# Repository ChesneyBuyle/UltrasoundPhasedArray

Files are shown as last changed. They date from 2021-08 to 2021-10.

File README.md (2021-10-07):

# UltrasoundPhasedArray
 Ultrasound phased array for directional transmission: construction, embedded software and python implementation

## General specifications
A low-cost, narrowband ultrasound phased array system for narrowbeam transmission is presented. 

The design features wide bandwidth MEMS loudspeakers (UT-P 2019, USound) with very small dimensions (5 x 7 mm). Dense loudspeaker arrays with small interelement spacing can be constructed, enabling grating lobe free beam patterns at high frequency. The current prototype can support up to 64 MEMS speakers. The amplitude and phase of each loudspeaker stage can be controlled with high resolution, respectively with 10-bit and 12-bit. The array itself is constructed using a 3D printer. 

<p align="center">
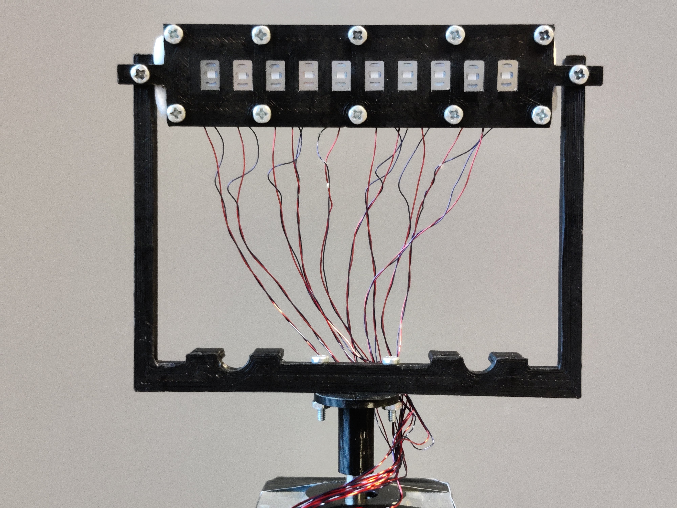
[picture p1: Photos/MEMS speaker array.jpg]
  
</p>

## System overview

Block diagram of the prototype:

<p align="center">
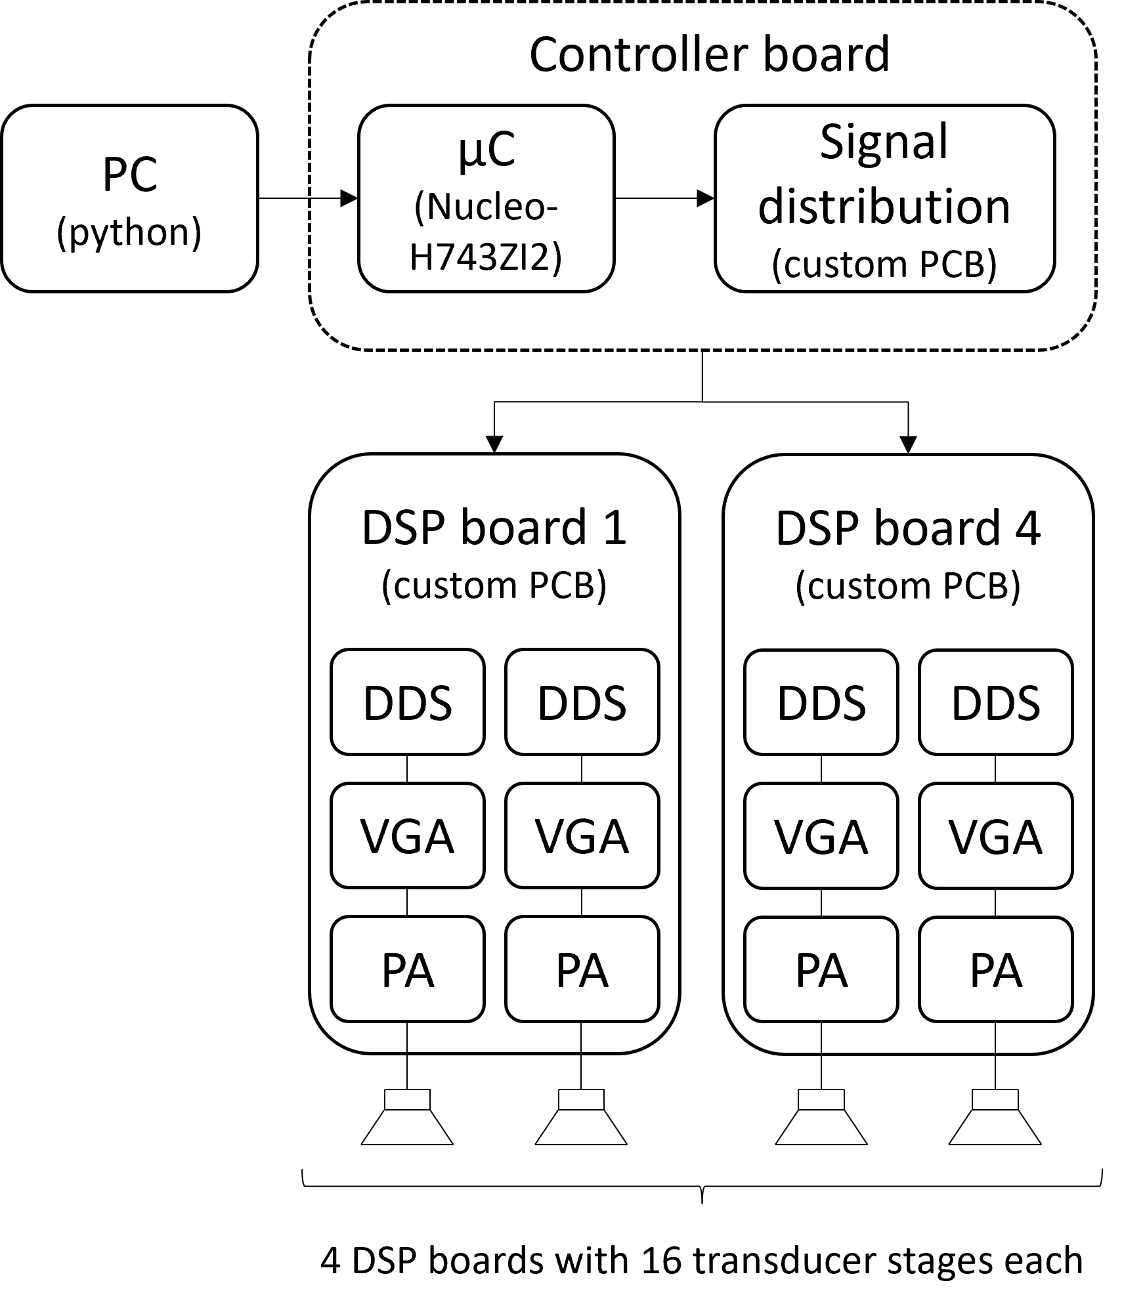
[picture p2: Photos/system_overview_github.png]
 
</p>

The loudspeaker array is controlled by an external computer. The phase delays and amplitudes of the loudspeaker stages are calculated according to the desired ultrasound beam pattern in Python. Next, these parameters are sent to a controller board, which consists of a NUCLEO-H743ZI2 microcontroller board and custom signal distribution PCB. 
* The microcontroller sends the transducer stage parameters to the corresponding DSP boards. The DSP boards contain the signal generation and amplifier hardware blocks of the loudspeaker stages. 
* The microcontroller uses the signal distribution board to distribute a common clock signal to the DSP boards (for phase coherence) and it ensures communication to the correct hardware blocks. 

## Folder structure
* The *3D prints* folder contains the necessary STL-files to print the array. The loudspeakers should first be placed inside the *holder part (part 1)*. Next, the *cover part (part 2)* can be attached to the back of the array (side with connections on the MEMS loudspeakers) using M2 bolts. This keeps the MEMS loudspeakers in place when soldering the signal wires. Hence, now you should be able to solder the signal wires to the loudspeaker elements. We used very thin 0.25mm coated copper wire, because the loudspeaker connections are very fragile. Finally, we placed a thin layer of acoustic foam on the back of array and kept it into place using the *wire cover part (part 3)*. It also ensures that the signal wires and thus MEMS loudspeakers do not move anymore. 

* The *Python* folder contains the Python scripts for control over the transducer stages (controller.py and main.py). Furthermore, the Python scripts for sampling of the microphone signal (daq.py), stepper motor control (stepper.py) and plotting (plotter.py) are also available. Note that some paths may need to updated before the code runs correctly.

* The *PCB design files* folder contains the schematic and board files of the custom signal distribution and DSP boards (DDS, VGA and power amplifier). These were designed in Eagle. 

* The *Controller board code* contains the embedded code for the NUCLEO-H743ZI2 microcontroller board.

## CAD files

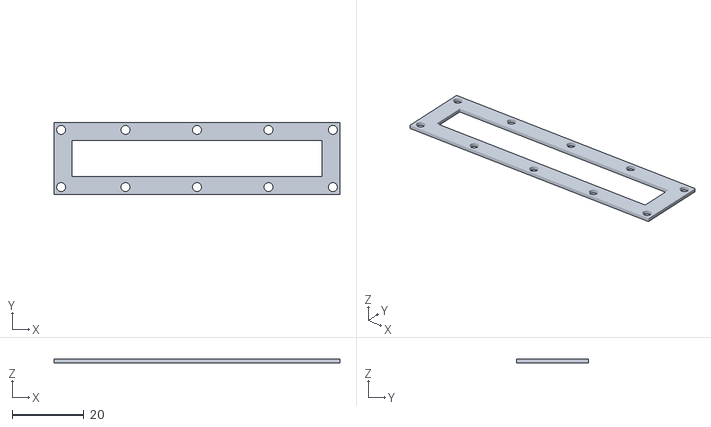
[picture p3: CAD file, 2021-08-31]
3D prints/1x10 loudspeaker array (part 3 - wire cover).stl
80.0 x 20.0 x 1.00

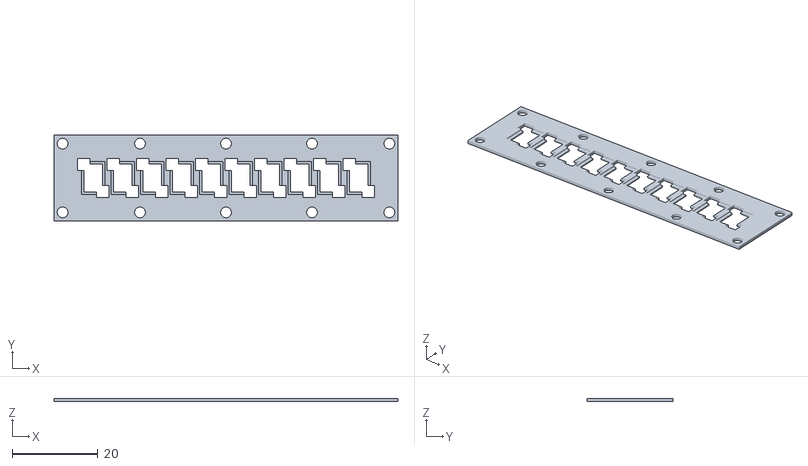
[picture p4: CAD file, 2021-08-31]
3D prints/1x10 loudspeaker array (part 2 - cover).stl
80.0 x 20.0 x 0.8

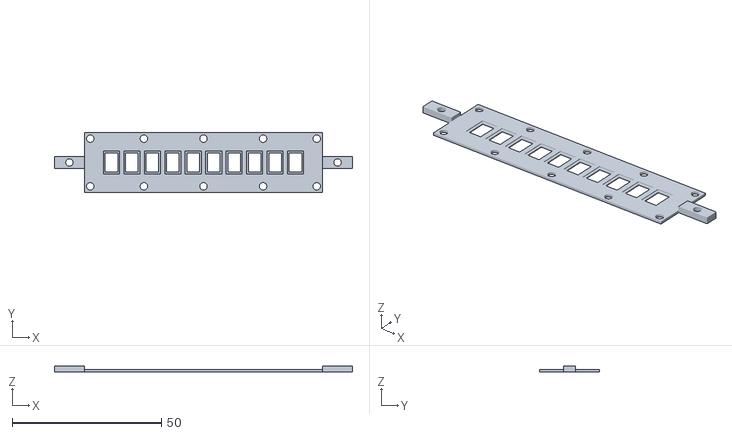
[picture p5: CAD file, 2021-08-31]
3D prints/1x10 loudspeaker array (part 1 - holder).stl
100.0 x 20.0 x 2.00

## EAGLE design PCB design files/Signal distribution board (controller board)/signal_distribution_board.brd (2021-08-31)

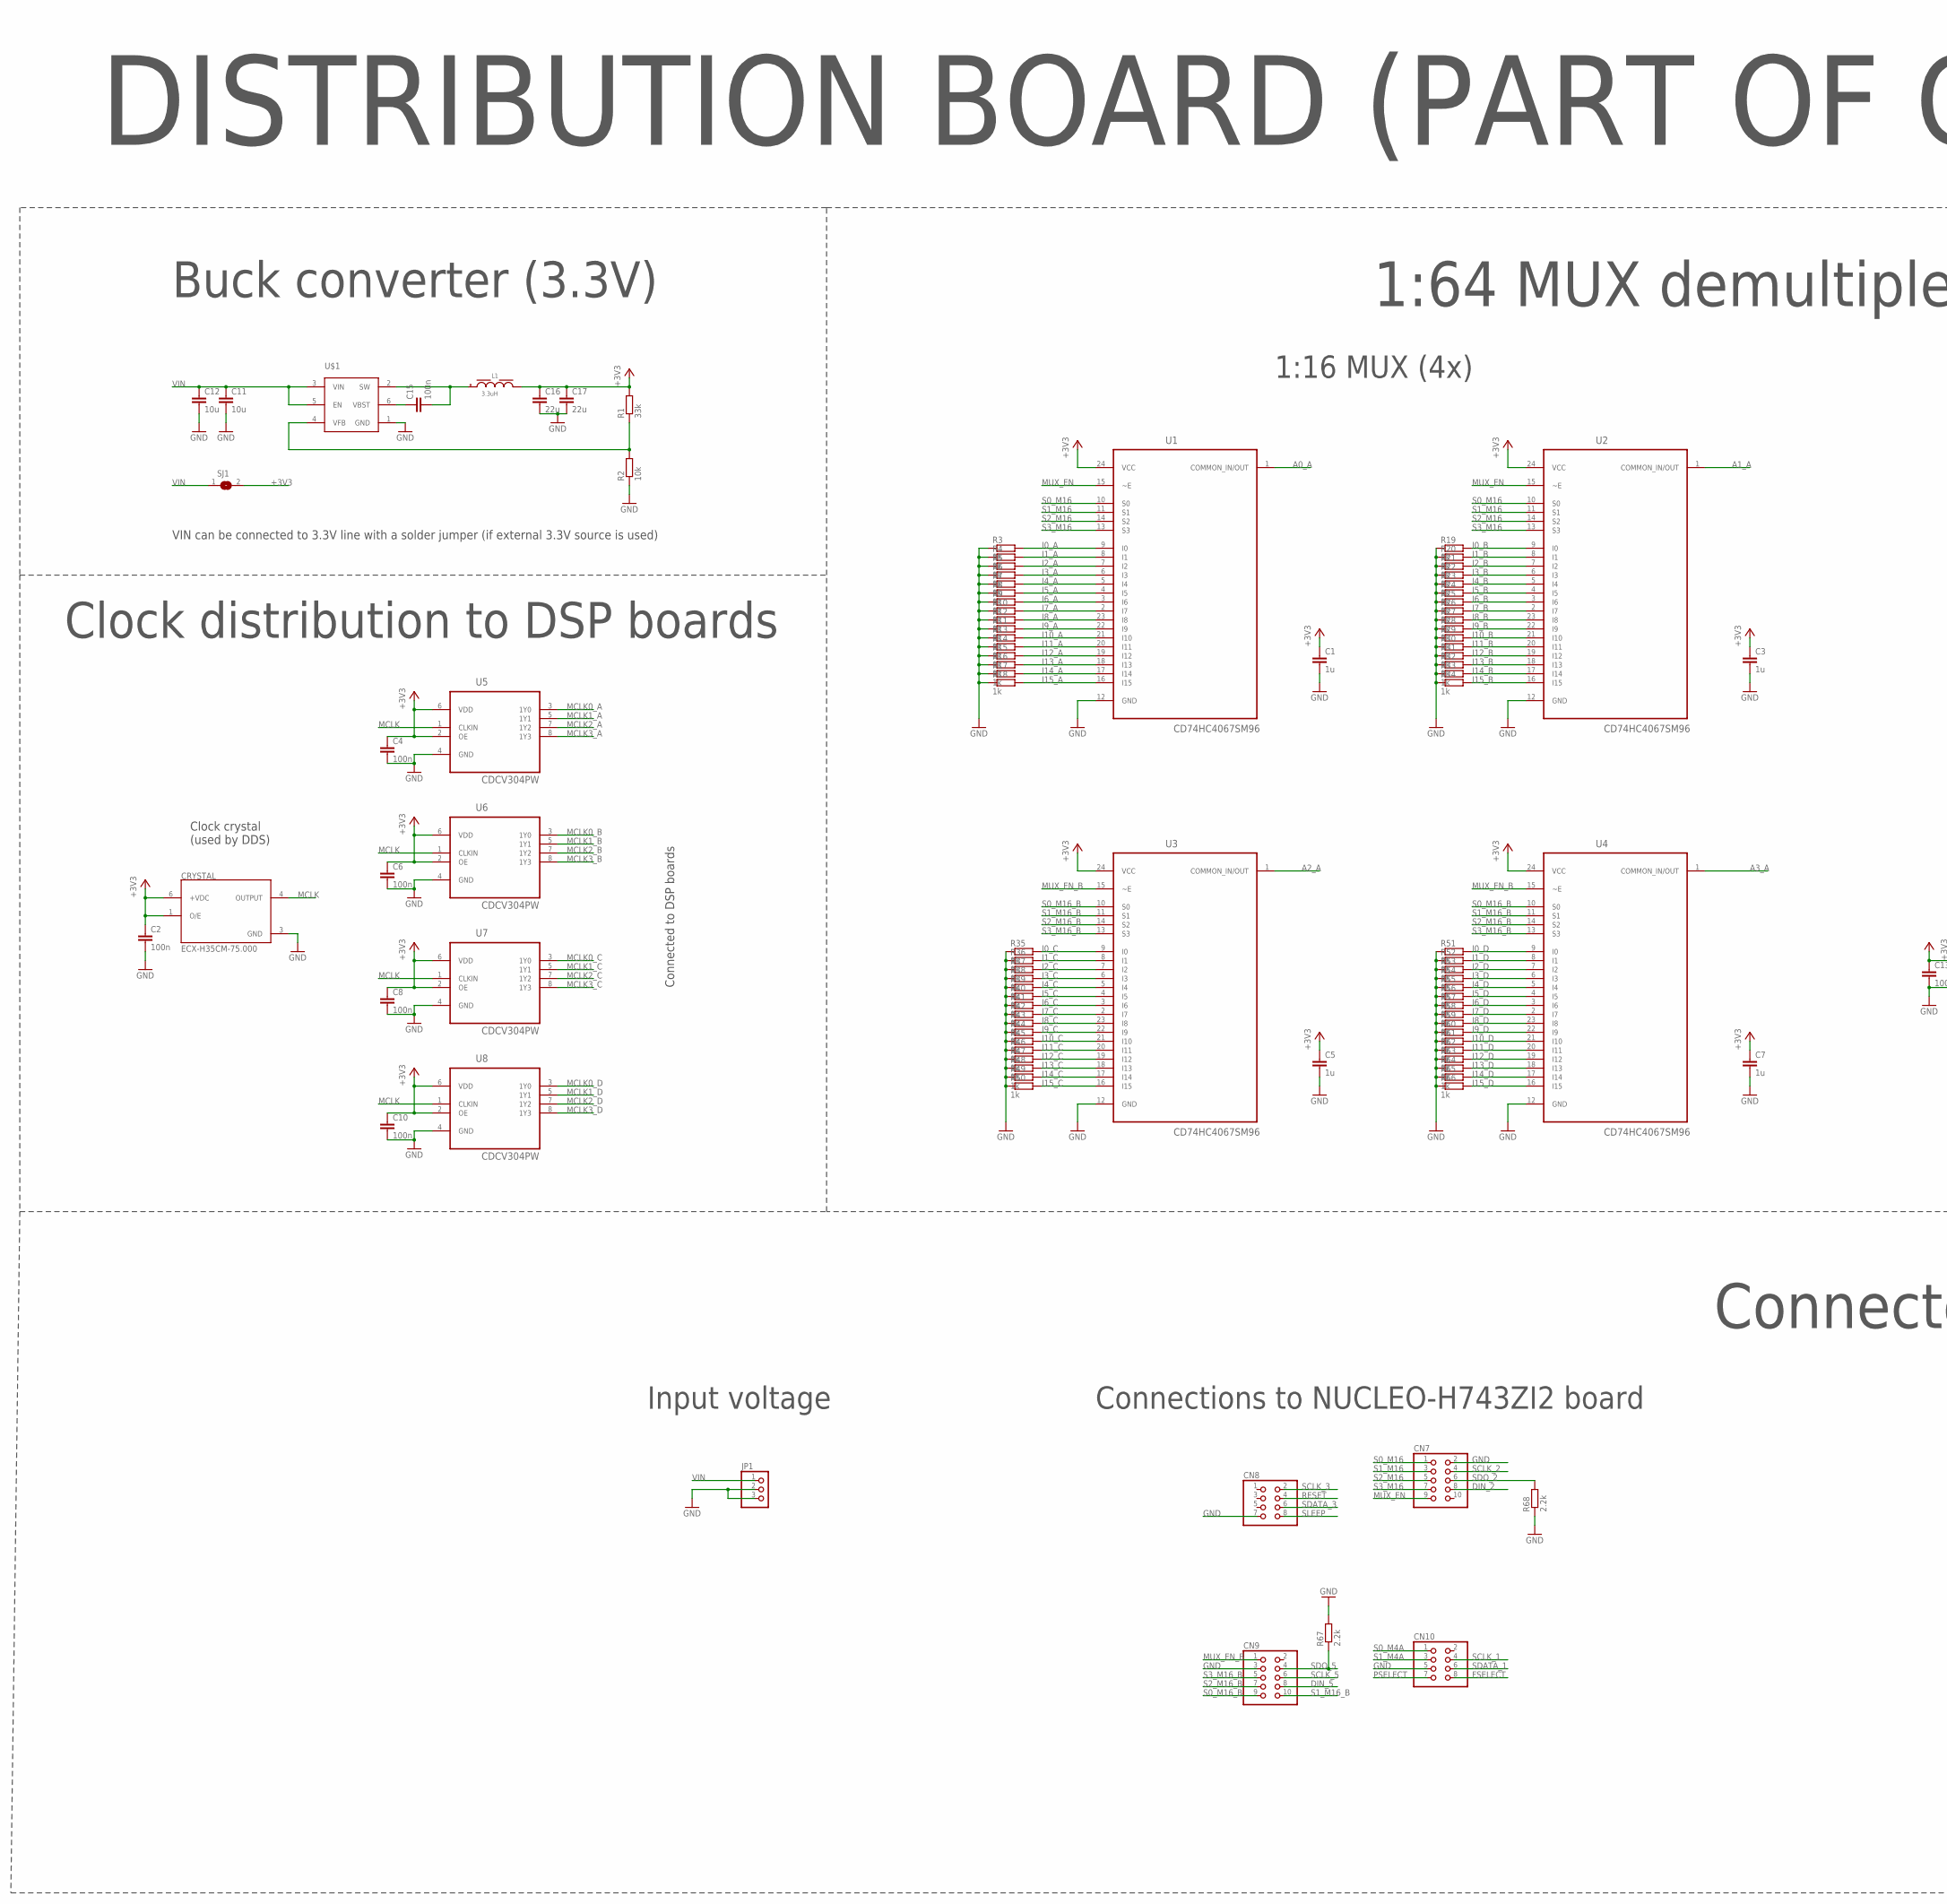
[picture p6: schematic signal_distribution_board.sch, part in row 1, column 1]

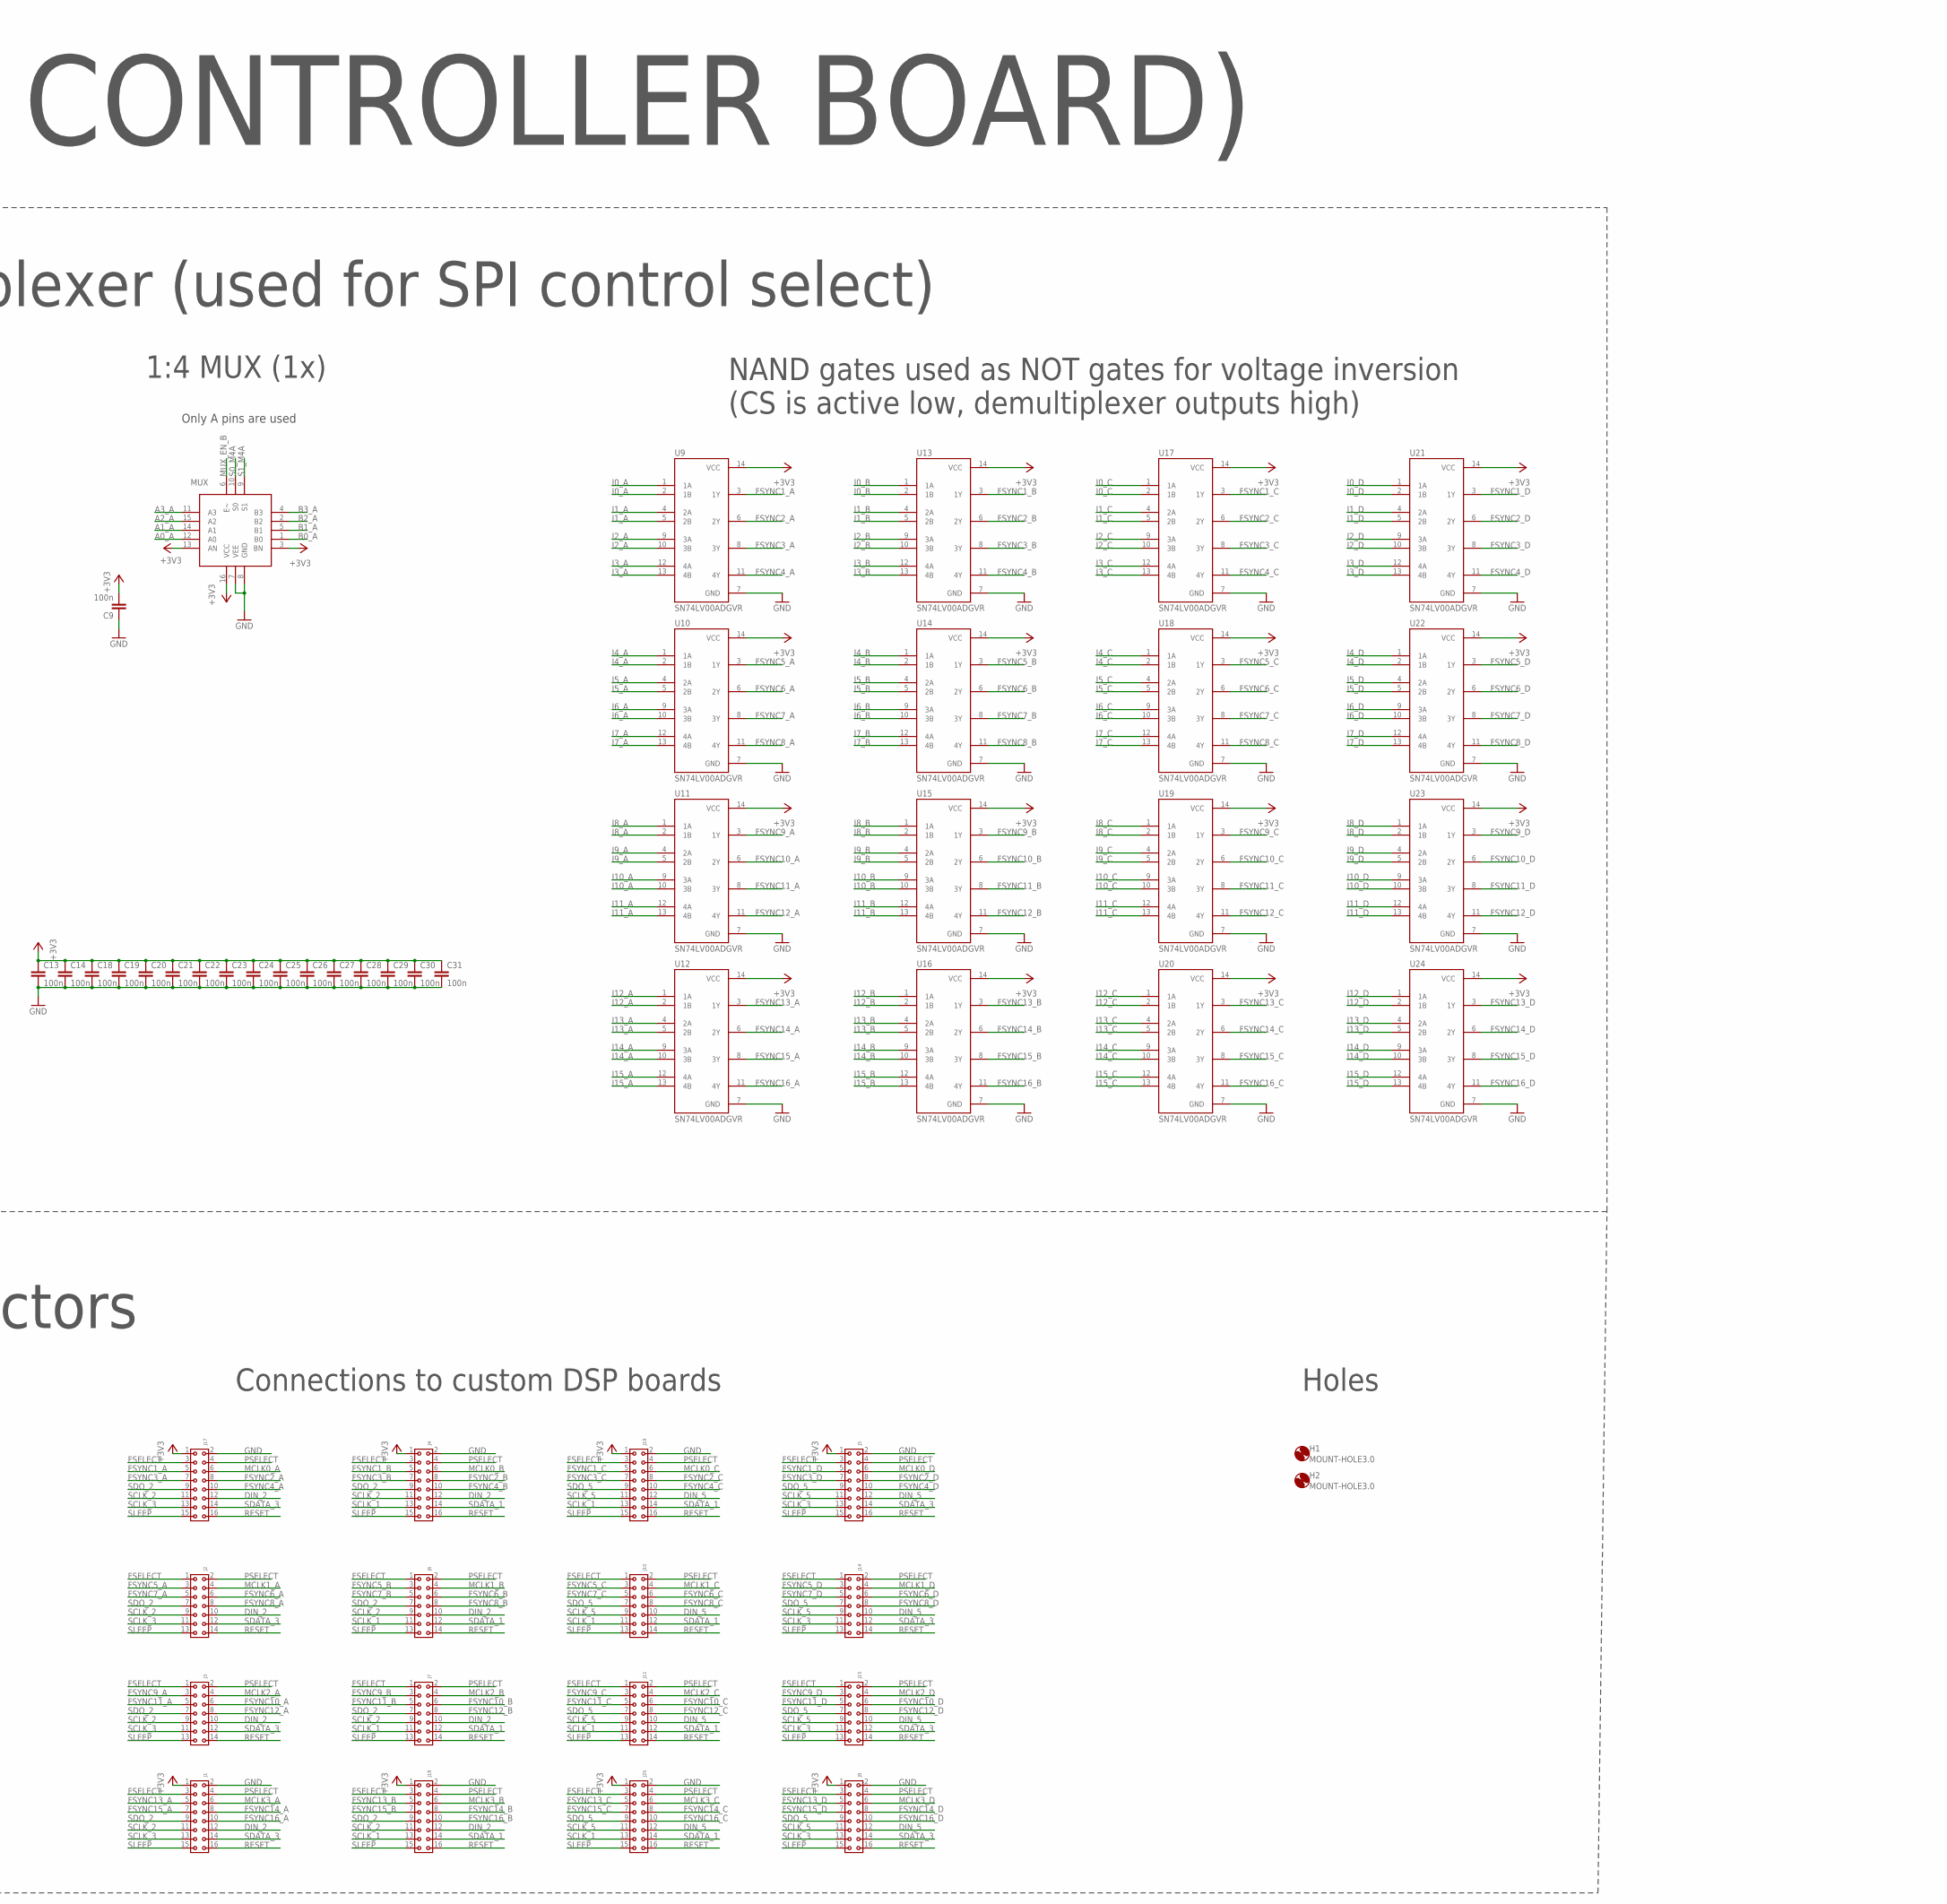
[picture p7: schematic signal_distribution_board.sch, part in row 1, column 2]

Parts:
C1, C3, C5, C7: 1u; C0603
C2, C4, C6, C8, C9, C10, C13, C14, C15, C18, C19, C20, C21, C22, C23, C24, C25, C26, C27, C28, C29, C30, C31: 100n; C0603
C11, C12: 10u; C0805
C16, C17: 22u; C1206
CN7, CN9: PINHD-2X5; 2X05
CN8, CN10: PINHD-2X4; 2X04
CRYSTAL: ECX-H35CM-75.000; OSC_ECX-H35CM-75.000
H1, H2: MOUNT-HOLE3.0; 3,0
J1, J4, J5, J8, J17, J18, J19, J20: 6130XX243121_613016243121; 613016243121
J2, J3, J6, J7, J10, J11, J14, J15: 6130XX243121_613014243121; 613014243121
JP1: PINHD-1X3; 1X03
L1: 3.3uH; WE-PD_7345P
MUX: CD74HC4052M96; SOIC127P600X175-16N
R1: 33k; R0603
R2: 10k; R0603
R3, R4, R5, R6, R7, R8, R9, R10, R11, R12, R13, R14, R15, R16, R17, R18, R19, R20, R21, R22, R23, R24, R25, R26, R27, R28, R29, R30, R31, R32, R33, R34, R35, R36, R37, R38, R39, R40, R41, R42, R43, R44, R45, R46, R47, R48, R49, R50, R51, R52, R53, R54, R55, R56, R57, R58, R59, R60, R61, R62, R63, R64, R65, R66: 1k; R0603
R67, R68: 2.2k; R0805
SJ1: SJ
U1, U2, U3, U4: CD74HC4067SM96; SOP65P780X200-24N
U5, U6, U7, U8: CDCV304PW; SOP65P640X120-8N
U9, U10, U11, U12, U13, U14, U15, U16, U17, U18, U19, U20, U21, U22, U23, U24: SN74LV00ADGVR; SOP40P640X120-14N
U$1: TPS562209; SOT95P280X110-6N

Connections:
+3V3: C1.1, C2.1, C3.1, C4.1, C5.1, C6.1, C7.1, C8.1, C9.2, C10.1, C13.1, C14.1, C16.1, C17.1, C18.1, C19.1, C20.1, C21.1, C22.1, C23.1, C24.1, C25.1, C26.1, C27.1, C28.1, C29.1, C30.1, C31.1, CRYSTAL.1 (O/E), CRYSTAL.6 (+VDC), J1.1, J4.1, J5.1, J8.1, J17.1, J18.1, J19.1, J20.1, L1.2, MUX.3 (BN), MUX.13 (AN), MUX.16 (VCC), R1.2, SJ1.2, U1.24 (VCC), U2.24 (VCC), U3.24 (VCC), U4.24 (VCC), U5.2 (OE), U5.6 (VDD), U6.2 (OE), U6.6 (VDD), U7.2 (OE), U7.6 (VDD), U8.2 (OE), U8.6 (VDD), U9.14 (VCC), U10.14 (VCC), U11.14 (VCC), U12.14 (VCC), U13.14 (VCC), U14.14 (VCC), U15.14 (VCC), U16.14 (VCC), U17.14 (VCC), U18.14 (VCC), U19.14 (VCC), U20.14 (VCC), U21.14 (VCC), U22.14 (VCC), U23.14 (VCC), U24.14 (VCC)
A0_A: MUX.12 (A0), U1.1 (COMMON_IN/OUT)
A1_A: MUX.14 (A1), U2.1 (COMMON_IN/OUT)
A2_A: MUX.15 (A2), U3.1 (COMMON_IN/OUT)
A3_A: MUX.11 (A3), U4.1 (COMMON_IN/OUT)
B0_A: MUX.1 (B0)
B1_A: MUX.5 (B1)
B2_A: MUX.2 (B2)
B3_A: MUX.4 (B3)
DIN_2: CN7.8, J1.12, J2.10, J3.10, J4.12, J6.10, J7.10, J17.12, J18.12
DIN_5: CN9.8, J5.12, J8.12, J10.10, J11.10, J14.10, J15.10, J19.12, J20.12
FSELECT: CN10.8, J1.3, J2.1, J3.1, J4.3, J5.3, J6.1, J7.1, J8.3, J10.1, J11.1, J14.1, J15.1, J17.3, J18.3, J19.3, J20.3
FSYNC1_A: J17.5, U9.3 (1Y)
FSYNC1_B: J4.5, U13.3 (1Y)
FSYNC1_C: J19.5, U17.3 (1Y)
FSYNC1_D: J5.5, U21.3 (1Y)
FSYNC2_A: J17.8, U9.6 (2Y)
FSYNC2_B: J4.8, U13.6 (2Y)
FSYNC2_C: J19.8, U17.6 (2Y)
FSYNC2_D: J5.8, U21.6 (2Y)
FSYNC3_A: J17.7, U9.8 (3Y)
FSYNC3_B: J4.7, U13.8 (3Y)
FSYNC3_C: J19.7, U17.8 (3Y)
FSYNC3_D: J5.7, U21.8 (3Y)
FSYNC4_A: J17.10, U9.11 (4Y)
FSYNC4_B: J4.10, U13.11 (4Y)
FSYNC4_C: J19.10, U17.11 (4Y)
FSYNC4_D: J5.10, U21.11 (4Y)
FSYNC5_A: J2.3, U10.3 (1Y)
FSYNC5_B: J6.3, U14.3 (1Y)
FSYNC5_C: J10.3, U18.3 (1Y)
FSYNC5_D: J14.3, U22.3 (1Y)
FSYNC6_A: J2.6, U10.6 (2Y)
FSYNC6_B: J6.6, U14.6 (2Y)
FSYNC6_C: J10.6, U18.6 (2Y)
FSYNC6_D: J14.6, U22.6 (2Y)
FSYNC7_A: J2.5, U10.8 (3Y)
FSYNC7_B: J6.5, U14.8 (3Y)
FSYNC7_C: J10.5, U18.8 (3Y)
FSYNC7_D: J14.5, U22.8 (3Y)
FSYNC8_A: J2.8, U10.11 (4Y)
FSYNC8_B: J6.8, U14.11 (4Y)
FSYNC8_C: J10.8, U18.11 (4Y)
FSYNC8_D: J14.8, U22.11 (4Y)
FSYNC9_A: J3.3, U11.3 (1Y)
FSYNC9_B: J7.3, U15.3 (1Y)
FSYNC9_C: J11.3, U19.3 (1Y)
FSYNC9_D: J15.3, U23.3 (1Y)
FSYNC10_A: J3.6, U11.6 (2Y)
FSYNC10_B: J7.6, U15.6 (2Y)
FSYNC10_C: J11.6, U19.6 (2Y)
FSYNC10_D: J15.6, U23.6 (2Y)
FSYNC11_A: J3.5, U11.8 (3Y)
FSYNC11_B: J7.5, U15.8 (3Y)
FSYNC11_C: J11.5, U19.8 (3Y)
FSYNC11_D: J15.5, U23.8 (3Y)
FSYNC12_A: J3.8, U11.11 (4Y)
FSYNC12_B: J7.8, U15.11 (4Y)
FSYNC12_C: J11.8, U19.11 (4Y)
FSYNC12_D: J15.8, U23.11 (4Y)
FSYNC13_A: J1.5, U12.3 (1Y)
FSYNC13_B: J18.5, U16.3 (1Y)
FSYNC13_C: J20.5, U20.3 (1Y)
FSYNC13_D: J8.5, U24.3 (1Y)
FSYNC14_A: J1.8, U12.6 (2Y)
FSYNC14_B: J18.8, U16.6 (2Y)
FSYNC14_C: J20.8, U20.6 (2Y)
FSYNC14_D: J8.8, U24.6 (2Y)
FSYNC15_A: J1.7, U12.8 (3Y)
FSYNC15_B: J18.7, U16.8 (3Y)
FSYNC15_C: J20.7, U20.8 (3Y)
FSYNC15_D: J8.7, U24.8 (3Y)
FSYNC16_A: J1.10, U12.11 (4Y)
FSYNC16_B: J18.10, U16.11 (4Y)
FSYNC16_C: J20.10, U20.11 (4Y)
FSYNC16_D: J8.10, U24.11 (4Y)
GND: C1.2, C2.2, C3.2, C4.2, C5.2, C6.2, C7.2, C8.2, C9.1, C10.2, C11.2, C12.2, C13.2, C14.2, C16.2, C17.2, C18.2, C19.2, C20.2, C21.2, C22.2, C23.2, C24.2, C25.2, C26.2, C27.2, C28.2, C29.2, C30.2, C31.2, CN7.2, CN8.7, CN9.3, CN10.5, CRYSTAL.3 (GND), J1.2, J4.2, J5.2, J8.2, J17.2, J18.2, J19.2, J20.2, JP1.2, JP1.3, MUX.7 (VEE), MUX.8 (GND), R2.1, R3.1, R4.1, R5.1, R6.1, R7.1, R8.1, R9.1, R10.1, R11.1, R12.1, R13.1, R14.1, R15.1, R16.1, R17.1, R18.1, R19.1, R20.1, R21.1, R22.1, R23.1, R24.1, R25.1, R26.1, R27.1, R28.1, R29.1, R30.1, R31.1, R32.1, R33.1, R34.1, R35.1, R36.1, R37.1, R38.1, R39.1, R40.1, R41.1, R42.1, R43.1, R44.1, R45.1, R46.1, R47.1, R48.1, R49.1, R50.1, R51.1, R52.1, R53.1, R54.1, R55.1, R56.1, R57.1, R58.1, R59.1, R60.1, R61.1, R62.1, R63.1, R64.1, R65.1, R66.1, R67.2, R68.1, U1.12 (GND), U2.12 (GND), U3.12 (GND), U4.12 (GND), U5.4 (GND), U6.4 (GND), U7.4 (GND), U8.4 (GND), U9.7 (GND), U10.7 (GND), U11.7 (GND), U12.7 (GND), U13.7 (GND), U14.7 (GND), U15.7 (GND), U16.7 (GND), U17.7 (GND), U18.7 (GND), U19.7 (GND), U20.7 (GND), U21.7 (GND), U22.7 (GND), U23.7 (GND), U24.7 (GND), U$1.1 (GND)
I0_A: R3.2, U1.9 (I0), U9.1 (1A), U9.2 (1B)
I0_B: R19.2, U2.9 (I0), U13.1 (1A), U13.2 (1B)
I0_C: R35.2, U3.9 (I0), U17.1 (1A), U17.2 (1B)
I0_D: R51.2, U4.9 (I0), U21.1 (1A), U21.2 (1B)
I1_A: R4.2, U1.8 (I1), U9.4 (2A), U9.5 (2B)
I1_B: R20.2, U2.8 (I1), U13.4 (2A), U13.5 (2B)
I1_C: R36.2, U3.8 (I1), U17.4 (2A), U17.5 (2B)
I1_D: R52.2, U4.8 (I1), U21.4 (2A), U21.5 (2B)
I2_A: R5.2, U1.7 (I2), U9.9 (3A), U9.10 (3B)
I2_B: R21.2, U2.7 (I2), U13.9 (3A), U13.10 (3B)
I2_C: R37.2, U3.7 (I2), U17.9 (3A), U17.10 (3B)
I2_D: R53.2, U4.7 (I2), U21.9 (3A), U21.10 (3B)
I3_A: R6.2, U1.6 (I3), U9.12 (4A), U9.13 (4B)
I3_B: R22.2, U2.6 (I3), U13.12 (4A), U13.13 (4B)
I3_C: R38.2, U3.6 (I3), U17.12 (4A), U17.13 (4B)
I3_D: R54.2, U4.6 (I3), U21.12 (4A), U21.13 (4B)
I4_A: R7.2, U1.5 (I4), U10.1 (1A), U10.2 (1B)
I4_B: R23.2, U2.5 (I4), U14.1 (1A), U14.2 (1B)
I4_C: R39.2, U3.5 (I4), U18.1 (1A), U18.2 (1B)
I4_D: R55.2, U4.5 (I4), U22.1 (1A), U22.2 (1B)
I5_A: R8.2, U1.4 (I5), U10.4 (2A), U10.5 (2B)
I5_B: R24.2, U2.4 (I5), U14.4 (2A), U14.5 (2B)
I5_C: R40.2, U3.4 (I5), U18.4 (2A), U18.5 (2B)
I5_D: R56.2, U4.4 (I5), U22.4 (2A), U22.5 (2B)
I6_A: R9.2, U1.3 (I6), U10.9 (3A), U10.10 (3B)
I6_B: R25.2, U2.3 (I6), U14.9 (3A), U14.10 (3B)
I6_C: R41.2, U3.3 (I6), U18.9 (3A), U18.10 (3B)
I6_D: R57.2, U4.3 (I6), U22.9 (3A), U22.10 (3B)
I7_A: R10.2, U1.2 (I7), U10.12 (4A), U10.13 (4B)
I7_B: R26.2, U2.2 (I7), U14.12 (4A), U14.13 (4B)
I7_C: R42.2, U3.2 (I7), U18.12 (4A), U18.13 (4B)
I7_D: R58.2, U4.2 (I7), U22.12 (4A), U22.13 (4B)
I8_A: R12.2, U1.23 (I8), U11.1 (1A), U11.2 (1B)
I8_B: R27.2, U2.23 (I8), U15.1 (1A), U15.2 (1B)
I8_C: R43.2, U3.23 (I8), U19.1 (1A), U19.2 (1B)
I8_D: R59.2, U4.23 (I8), U23.1 (1A), U23.2 (1B)
I9_A: R11.2, U1.22 (I9), U11.4 (2A), U11.5 (2B)
I9_B: R28.2, U2.22 (I9), U15.4 (2A), U15.5 (2B)
I9_C: R44.2, U3.22 (I9), U19.4 (2A), U19.5 (2B)
I9_D: R60.2, U4.22 (I9), U23.4 (2A), U23.5 (2B)
I10_A: R13.2, U1.21 (I10), U11.9 (3A), U11.10 (3B)
I10_B: R29.2, U2.21 (I10), U15.9 (3A), U15.10 (3B)
I10_C: R45.2, U3.21 (I10), U19.9 (3A), U19.10 (3B)
I10_D: R61.2, U4.21 (I10), U23.9 (3A), U23.10 (3B)
I11_A: R14.2, U1.20 (I11), U11.12 (4A), U11.13 (4B)
I11_B: R30.2, U2.20 (I11), U15.12 (4A), U15.13 (4B)
I11_C: R46.2, U3.20 (I11), U19.12 (4A), U19.13 (4B)
I11_D: R62.2, U4.20 (I11), U23.12 (4A), U23.13 (4B)
I12_A: R15.2, U1.19 (I12), U12.1 (1A), U12.2 (1B)
I12_B: R31.2, U2.19 (I12), U16.1 (1A), U16.2 (1B)
I12_C: R47.2, U3.19 (I12), U20.1 (1A), U20.2 (1B)
I12_D: R63.2, U4.19 (I12), U24.1 (1A), U24.2 (1B)
I13_A: R16.2, U1.18 (I13), U12.4 (2A), U12.5 (2B)
I13_B: R32.2, U2.18 (I13), U16.4 (2A), U16.5 (2B)
I13_C: R48.2, U3.18 (I13), U20.4 (2A), U20.5 (2B)
I13_D: R64.2, U4.18 (I13), U24.4 (2A), U24.5 (2B)
I14_A: R17.2, U1.17 (I14), U12.9 (3A), U12.10 (3B)
I14_B: R33.2, U2.17 (I14), U16.9 (3A), U16.10 (3B)
I14_C: R49.2, U3.17 (I14), U20.9 (3A), U20.10 (3B)
I14_D: R65.2, U4.17 (I14), U24.9 (3A), U24.10 (3B)
I15_A: R18.2, U1.16 (I15), U12.12 (4A), U12.13 (4B)
I15_B: R34.2, U2.16 (I15), U16.12 (4A), U16.13 (4B)
I15_C: R50.2, U3.16 (I15), U20.12 (4A), U20.13 (4B)
I15_D: R66.2, U4.16 (I15), U24.12 (4A), U24.13 (4B)
MCLK: CRYSTAL.4 (OUTPUT), U5.1 (CLKIN), U6.1 (CLKIN), U7.1 (CLKIN), U8.1 (CLKIN)
MCLK0_A: J17.6, U5.3 (1Y0)
MCLK0_B: J4.6, U6.3 (1Y0)
MCLK0_C: J19.6, U7.3 (1Y0)
MCLK0_D: J5.6, U8.3 (1Y0)
MCLK1_A: J2.4, U5.5 (1Y1)
MCLK1_B: J6.4, U6.5 (1Y1)
MCLK1_C: J10.4, U7.5 (1Y1)
MCLK1_D: J14.4, U8.5 (1Y1)
MCLK2_A: J3.4, U5.7 (1Y2)
MCLK2_B: J7.4, U6.7 (1Y2)
MCLK2_C: J11.4, U7.7 (1Y2)
MCLK2_D: J15.4, U8.7 (1Y2)
MCLK3_A: J1.6, U5.8 (1Y3)
MCLK3_B: J18.6, U6.8 (1Y3)
MCLK3_C: J20.6, U7.8 (1Y3)
MCLK3_D: J8.6, U8.8 (1Y3)
MUX_EN: CN7.9, U1.15 (~E), U2.15 (~E)
MUX_EN_B: CN9.1, MUX.6 (E~), U3.15 (~E), U4.15 (~E)
unnamed: C15.1, U$1.6 (VBST)
unnamed: R1.1, R2.2, U$1.4 (VFB)
unnamed: C15.2, L1.1, U$1.2 (SW)
PSELECT: CN10.7, J1.4, J2.2, J3.2, J4.4, J5.4, J6.2, J7.2, J8.4, J10.2, J11.2, J14.2, J15.2, J17.4, J18.4, J19.4, J20.4
RESET: CN8.4, J1.16, J2.14, J3.14, J4.16, J5.16, J6.14, J7.14, J8.16, J10.14, J11.14, J14.14, J15.14, J17.16, J18.16, J19.16, J20.16
S0_M4A: CN10.1, MUX.10 (S0)
S0_M16: CN7.1, U1.10 (S0), U2.10 (S0)
S0_M16_B: CN9.9, U3.10 (S0), U4.10 (S0)
S1_M4A: CN10.3, MUX.9 (S1)
S1_M16: CN7.3, U1.11 (S1), U2.11 (S1)
S1_M16_B: CN9.10, U3.11 (S1), U4.11 (S1)
S2_M16: CN7.5, U1.14 (S2), U2.14 (S2)
S2_M16_B: CN9.7, U3.14 (S2), U4.14 (S2)
S3_M16: CN7.7, U1.13 (S3), U2.13 (S3)
S3_M16_B: CN9.5, U3.13 (S3), U4.13 (S3)
SCLK_1: CN10.4, J4.13, J6.11, J7.11, J10.11, J11.11, J18.13, J19.13, J20.13
SCLK_2: CN7.4, J1.11, J2.9, J3.9, J4.11, J6.9, J7.9, J17.11, J18.11
SCLK_3: CN8.2, J1.13, J2.11, J3.11, J5.13, J8.13, J14.11, J15.11, J17.13
SCLK_5: CN9.6, J5.11, J8.11, J10.9, J11.9, J14.9, J15.9, J19.11, J20.11
SDATA_1: CN10.6, J4.14, J6.12, J7.12, J10.12, J11.12, J18.14, J19.14, J20.14
SDATA_3: CN8.6, J1.14, J2.12, J3.12, J5.14, J8.14, J14.12, J15.12, J17.14
SDO_2: CN7.6, J1.9, J2.7, J3.7, J4.9, J6.7, J7.7, J17.9, J18.9, R68.2
SDO_5: CN9.4, J5.9, J8.9, J10.7, J11.7, J14.7, J15.7, J19.9, J20.9, R67.1
SLEEP: CN8.8, J1.15, J2.13, J3.13, J4.15, J5.15, J6.13, J7.13, J8.15, J10.13, J11.13, J14.13, J15.13, J17.15, J18.15, J19.15, J20.15
VIN: C11.1, C12.1, JP1.1, SJ1.1, U$1.3 (VIN), U$1.5 (EN)

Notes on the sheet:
Clock distribution to DSP boards
Buck converter (3.3V)
Connectors
1:64 MUX demultiplexer (used for SPI control select)
VIN can be connected to 3.3V line with a solder jumper (if external 3.3V source is used)
Connected to DSP boards
Clock crystal (used by DDS)
1:16 MUX (4x)
1:4 MUX (1x)
Only A pins are used
NAND gates used as NOT gates for voltage inversion (CS is active low, demultiplexer outputs high)
Connections to NUCLEO-H743ZI2 board
Input voltage
Connections to custom DSP boards
Holes
DISTRIBUTION BOARD (PART OF CONTROLLER BOARD)

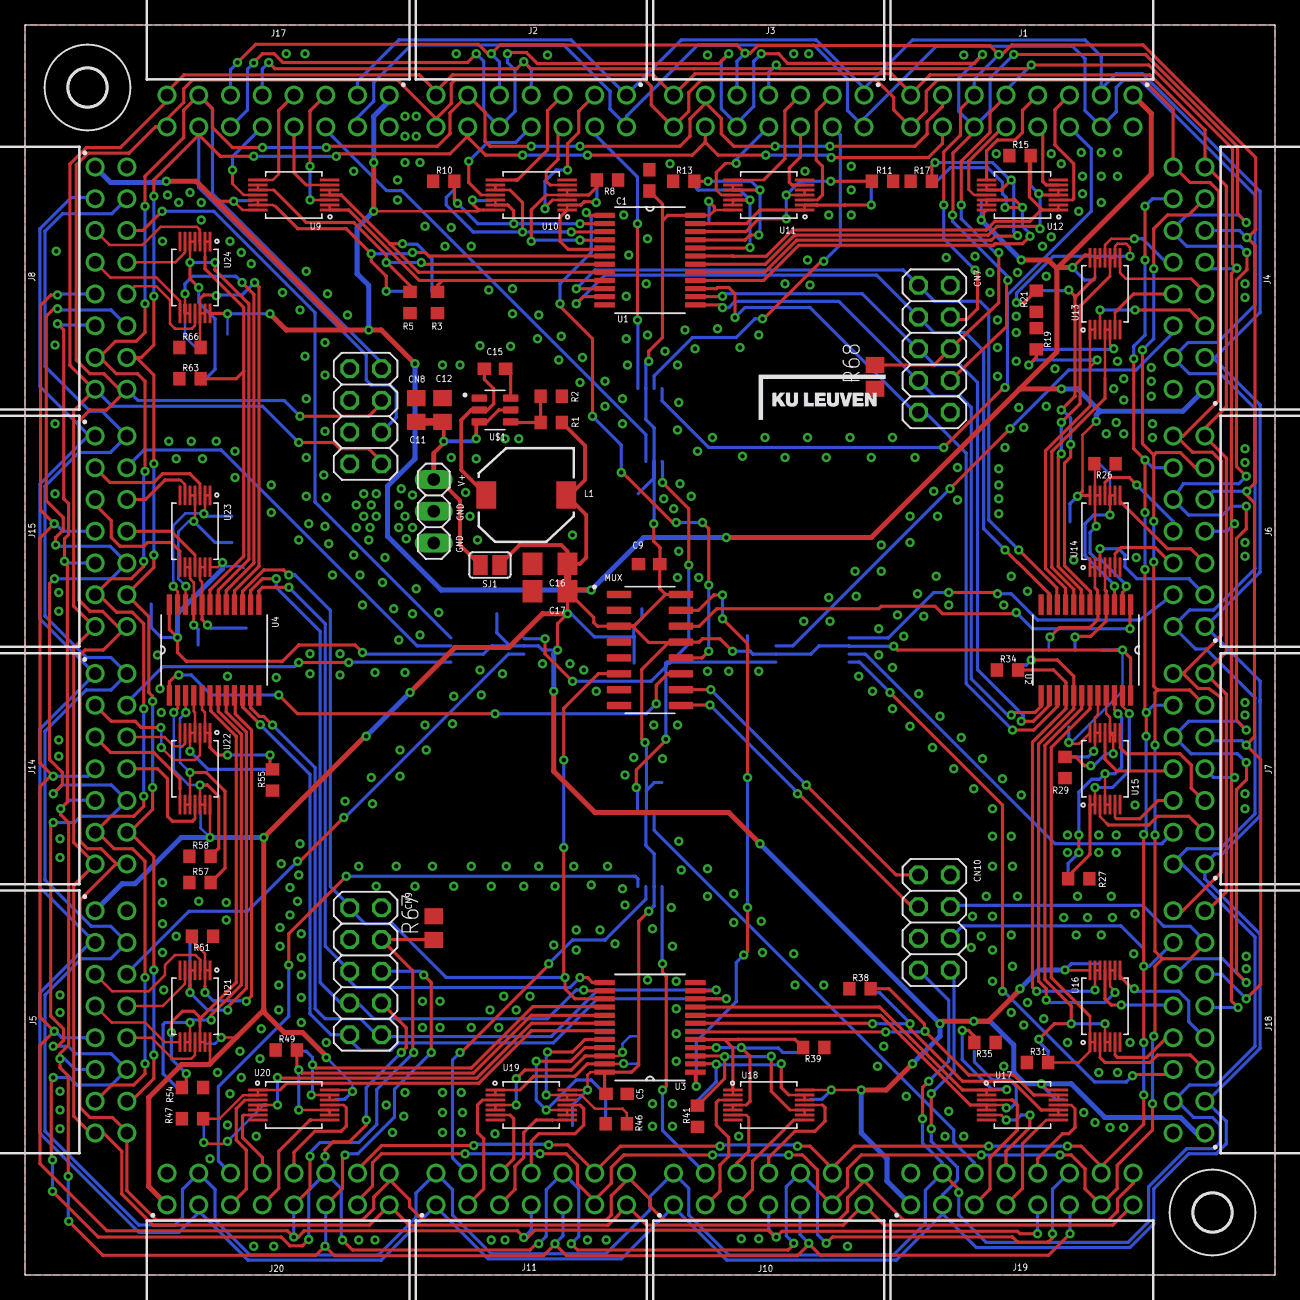
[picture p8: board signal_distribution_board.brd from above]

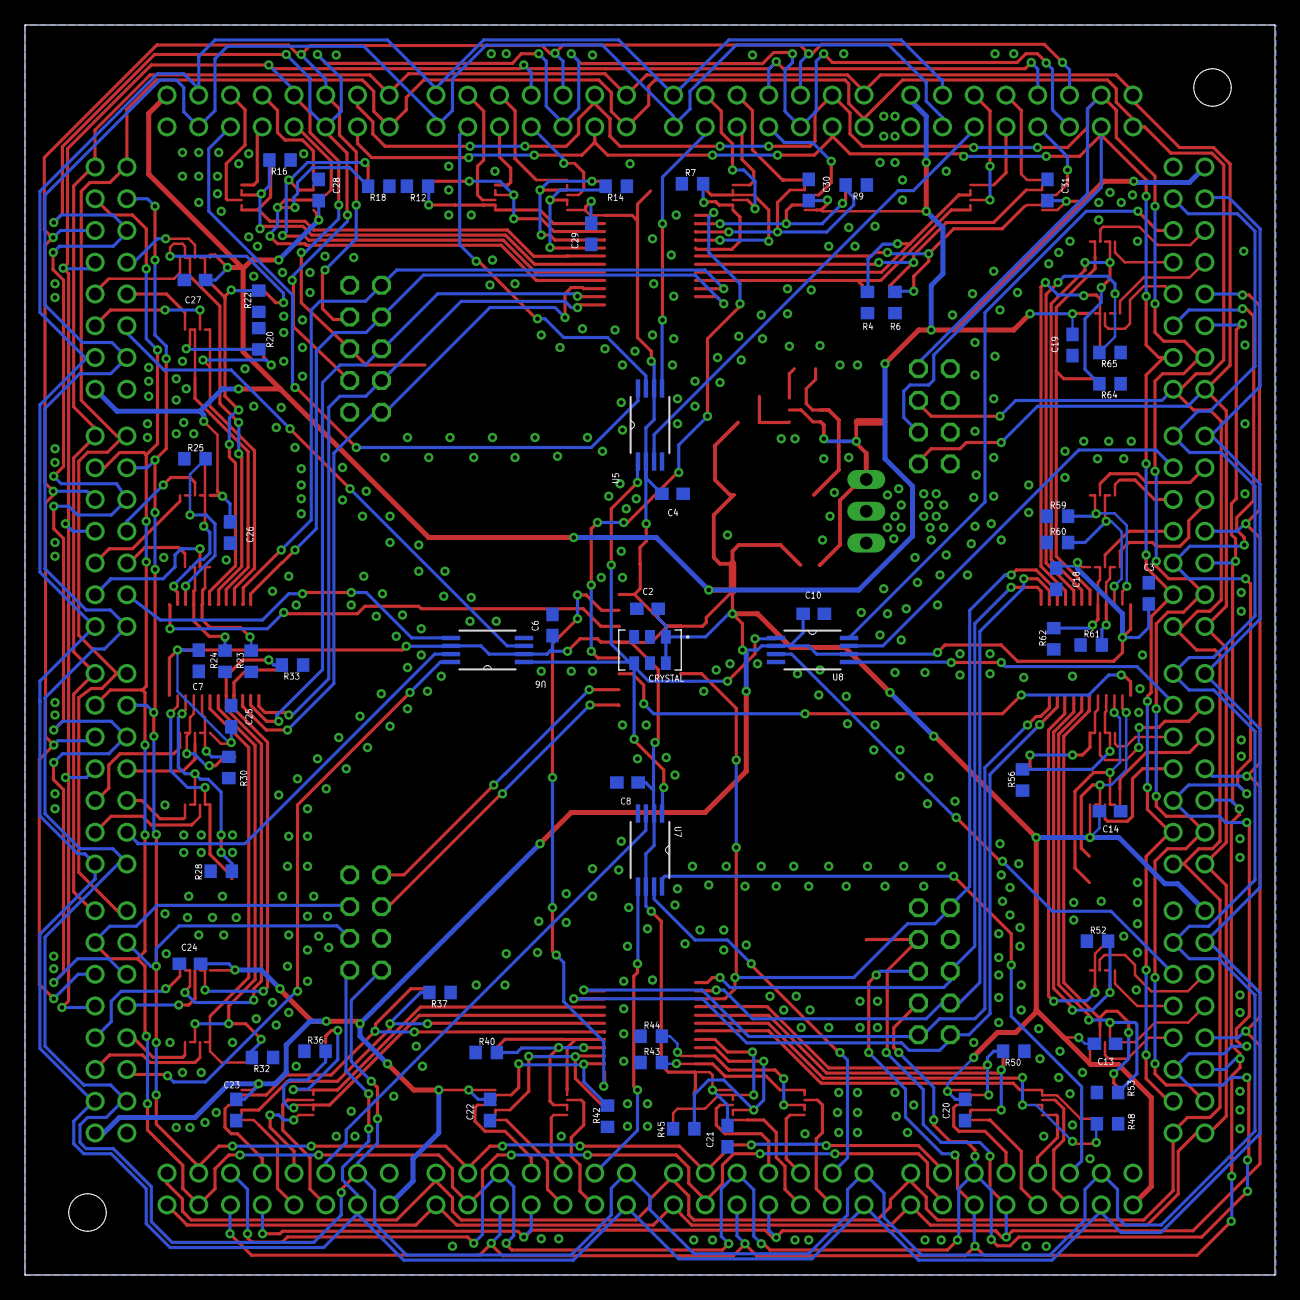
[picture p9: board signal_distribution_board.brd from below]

Board: 2 copper layers, 100.0 x 100.0 mm, 151 parts (63 on the bottom side), 181 nets.

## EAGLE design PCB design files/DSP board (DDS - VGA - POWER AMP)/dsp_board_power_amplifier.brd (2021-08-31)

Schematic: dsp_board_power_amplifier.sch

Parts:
C1, C19, C28, C37, C55, C64, C73, C91, C100, C109, C127, C136, C154, C172, C190, C208: 1u@6.3V; C0805
C2, C20, C29, C38, C56, C65, C74, C92, C101, C110, C128, C137, C155, C173, C191, C209: 1u6.3V; C0805
C3, C21, C30, C39, C57, C66, C75, C93, C102, C111, C129, C138, C156, C174, C192, C210: 1u; C0603
C4, C11, C12, C22, C31, C40, C47, C48, C58, C67, C76, C84, C85, C94, C103, C112, C121, C122, C130, C139, C157, C175, C193, C211: 10u; C0805
C5, C26, C35, C44, C62, C71, C80, C98, C107, C116, C134, C143, C161, C179, C197, C215: 1u@10V; C0603
C6, C27, C36, C45, C63, C72, C81, C99, C108, C117, C135, C144, C162, C180, C198, C216: 4.7u@25V; C0603
C7, C8, C23, C24, C32, C33, C41, C42, C59, C60, C68, C69, C77, C78, C95, C96, C104, C105, C113, C114, C131, C132, C140, C141, C158, C159, C176, C177, C194, C195, C212, C213: 1u@35V; C0603
C9, C25, C34, C43, C61, C70, C79, C97, C106, C115, C133, C142, C160, C178, C196, C214: 1u@25V; C0603
C10, C13, C14: 100 µF; WCAP-ASLU_6.3X7.7(DXL)
C15, C49, C86, C123: 100n; C0603
C16, C17, C50, C51, C87, C88, C124, C125: 22u; C1206
INPUT: 1935161; PHOENIX_1935161
JP1, JP2, JP5, JP6, JP7, JP8, JP9, JP10, JP13, JP14, JP15, JP16, JP17, JP18, JP21, JP22, JP23, JP24, JP25, JP26, JP29, JP30, JP31, JP32, JP35, JP36, JP39, JP40, JP43, JP44, JP47, JP48: PINHD-1X2; 1X02
L1, L5, L7, L9, L13, L15, L17, L21, L23, L25, L29, L31, L35, L39, L43, L47: BRL3225T4R7M 4.7u; INDC3225X170N
L2, L11, L19, L27: 3.3uH; WE-PD_7345P
L3, L6, L8, L10, L14, L16, L18, L22, L24, L26, L30, L32, L36, L40, L44, L48: FDSD0420-H-100M=P3; IND_FDSD0420-H-100M=P3
LSP1, LSP2, LSP3, LSP4: LSP10
R1, R2, R4, R12, R13, R14, R19, R20, R25, R26, R34, R37, R38, R43, R44, R49, R50, R56, R61, R62, R67, R68, R73, R74, R85, R86, R91, R92, R103, R104, R115, R116, R127, R128, R139, R140: 10k; R0603
R3, R11, R33, R55: 33k; R0603
R5, R6, R15, R16, R21, R22, R27, R28, R39, R40, R45, R46, R51, R52, R63, R64, R69, R70, R75, R76, R87, R88, R93, R94, R105, R106, R117, R118, R129, R130, R141, R142: 10; R0603
R7, R17, R23, R29, R41, R47, R53, R65, R71, R77, R89, R95, R107, R119, R131, R143: 18k; R0603
R8, R18, R24, R30, R42, R48, R54, R66, R72, R78, R90, R96, R108, R120, R132, R144: 1k; R0603
SJ1, SJ2, SJ5, SJ7, SJ9, SJ11, SJ13, SJ15, SJ17, SJ19, SJ21, SJ23, SJ25, SJ27, SJ29, SJ31, SJ35, SJ39, SJ43, SJ47: SJ
SJ3, SJ6, SJ8, SJ10, SJ14, SJ16, SJ18, SJ22, SJ24, SJ26, SJ30, SJ32, SJ36, SJ40, SJ44, SJ48: SJ2W; SJ_2
U1, U6, U8, U10, U14, U16, U18, U22, U24, U26, U30, U32, U36, U40, U44, U48: TLV61046ADBVR; SOT95P280X145-6N
U2, U5, U7, U9, U13, U15, U17, U21, U23, U25, U29, U31, U35, U39, U43, U47: LM48580; BGA12N40P3X4_119X159X62N
U$1, U$10, U$17, U$21: TPS562209; SOT95P280X110-6N
U$2, U$3, U$4, U$5, U$7, U$8, U$9, U$11, U$12, U$13, U$15, U$16, U$18, U$20, U$22, U$24: NSR0520V2T1G; SOD523

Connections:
15V_1: C6.1, R1.2, R7.2, U1.5 (VOUT)
15V_2: C27.1, R13.2, R17.2, U6.5 (VOUT)
15V_3: C45.1, R25.2, R29.2, U10.5 (VOUT)
15V_4: C63.1, R37.2, R41.2, U14.5 (VOUT)
15V_5: C81.1, R49.2, R53.2, U18.5 (VOUT)
15V_6: C99.1, R61.2, R65.2, U22.5 (VOUT)
15V_7: C117.1, R73.2, R77.2, U26.5 (VOUT)
15V_8: C135.1, R85.2, R89.2, U30.5 (VOUT)
15V_9: C36.1, R19.2, R23.2, U8.5 (VOUT)
15V_10: C72.1, R43.2, R47.2, U16.5 (VOUT)
15V_11: C108.1, R67.2, R71.2, U24.5 (VOUT)
15V_12: C144.1, R91.2, R95.2, U32.5 (VOUT)
15V_13: C162.1, R103.2, R107.2, U36.5 (VOUT)
15V_14: C180.1, R115.2, R119.2, U40.5 (VOUT)
15V_15: C198.1, R127.2, R131.2, U44.5 (VOUT)
15V_16: C216.1, R139.2, R143.2, U48.5 (VOUT)
+3V3_A: C3.1, C4.1, C5.1, C16.1, C17.1, C21.1, C22.1, C26.1, C39.1, C40.1, C44.1, C57.1, C58.1, C62.1, L1.1, L2.2, L3.1, L5.1, L6.1, L9.1, L10.1, L13.1, L14.1, R3.2, SJ1.2, SJ3.1, SJ6.1, SJ10.1, SJ14.1, U1.4 (EN), U1.6 (VIN), U2.C2 (~SHDN), U2.C3 (VDD), U5.C2 (~SHDN), U5.C3 (VDD), U6.4 (EN), U6.6 (VIN), U9.C2 (~SHDN), U9.C3 (VDD), U10.4 (EN), U10.6 (VIN), U13.C2 (~SHDN), U13.C3 (VDD), U14.4 (EN), U14.6 (VIN)
+3V3_B: C50.1, C51.1, C75.1, C76.1, C80.1, C93.1, C94.1, C98.1, C111.1, C112.1, C116.1, C129.1, C130.1, C134.1, L11.2, L17.1, L18.1, L21.1, L22.1, L25.1, L26.1, L29.1, L30.1, R11.2, SJ11.2, SJ18.1, SJ22.1, SJ26.1, SJ30.1, U17.C2 (~SHDN), U17.C3 (VDD), U18.4 (EN), U18.6 (VIN), U21.C2 (~SHDN), U21.C3 (VDD), U22.4 (EN), U22.6 (VIN), U25.C2 (~SHDN), U25.C3 (VDD), U26.4 (EN), U26.6 (VIN), U29.C2 (~SHDN), U29.C3 (VDD), U30.4 (EN), U30.6 (VIN)
+3V3_C: C30.1, C31.1, C35.1, C66.1, C67.1, C71.1, C87.1, C88.1, C102.1, C103.1, C107.1, C138.1, C139.1, C143.1, L7.1, L8.1, L15.1, L16.1, L19.2, L23.1, L24.1, L31.1, L32.1, R33.2, SJ8.1, SJ16.1, SJ19.2, SJ24.1, SJ32.1, U7.C2 (~SHDN), U7.C3 (VDD), U8.4 (EN), U8.6 (VIN), U15.C2 (~SHDN), U15.C3 (VDD), U16.4 (EN), U16.6 (VIN), U23.C2 (~SHDN), U23.C3 (VDD), U24.4 (EN), U24.6 (VIN), U31.C2 (~SHDN), U31.C3 (VDD), U32.4 (EN), U32.6 (VIN)
+3V3_D: C124.1, C125.1, C156.1, C157.1, C161.1, C174.1, C175.1, C179.1, C192.1, C193.1, C197.1, C210.1, C211.1, C215.1, L27.2, L35.1, L36.1, L39.1, L40.1, L43.1, L44.1, L47.1, L48.1, R55.2, SJ27.2, SJ36.1, SJ40.1, SJ44.1, SJ48.1, U35.C2 (~SHDN), U35.C3 (VDD), U36.4 (EN), U36.6 (VIN), U39.C2 (~SHDN), U39.C3 (VDD), U40.4 (EN), U40.6 (VIN), U43.C2 (~SHDN), U43.C3 (VDD), U44.4 (EN), U44.6 (VIN), U47.C2 (~SHDN), U47.C3 (VDD), U48.4 (EN), U48.6 (VIN)
GND: C3.2, C4.2, C5.2, C6.2, C9.1, C10.2 (-), C11.2, C12.2, C13.2 (-), C14.2 (-), C16.2, C17.2, C21.2, C22.2, C25.1, C26.2, C27.2, C30.2, C31.2, C34.1, C35.2, C36.2, C39.2, C40.2, C43.1, C44.2, C45.2, C47.2, C48.2, C50.2, C51.2, C57.2, C58.2, C61.1, C62.2, C63.2, C66.2, C67.2, C70.1, C71.2, C72.2, C75.2, C76.2, C79.1, C80.2, C81.2, C84.2, C85.2, C87.2, C88.2, C93.2, C94.2, C97.1, C98.2, C99.2, C102.2, C103.2, C106.1, C107.2, C108.2, C111.2, C112.2, C115.1, C116.2, C117.2, C121.2, C122.2, C124.2, C125.2, C129.2, C130.2, C133.1, C134.2, C135.2, C138.2, C139.2, C142.1, C143.2, C144.2, C156.2, C157.2, C160.1, C161.2, C162.2, C174.2, C175.2, C178.1, C179.2, C180.2, C192.2, C193.2, C196.1, C197.2, C198.2, C210.2, C211.2, C214.1, C215.2, C216.2, INPUT.2, LSP2.MP, LSP4.MP, R2.1, R4.1, R8.1, R12.1, R14.1, R18.1, R20.1, R24.1, R26.1, R30.1, R34.1, R38.1, R42.1, R44.1, R48.1, R50.1, R54.1, R56.1, R62.1, R66.1, R68.1, R72.1, R74.1, R78.1, R86.1, R90.1, R92.1, R96.1, R104.1, R108.1, R116.1, R120.1, R128.1, R132.1, R140.1, R144.1, SJ2.1, SJ3.3, SJ5.1, SJ6.3, SJ7.1, SJ8.3, SJ9.1, SJ10.3, SJ13.1, SJ14.3, SJ15.1, SJ16.3, SJ17.1, SJ18.3, SJ21.1, SJ22.3, SJ23.1, SJ24.3, SJ25.1, SJ26.3, SJ29.1, SJ30.3, SJ31.1, SJ32.3, SJ35.1, SJ36.3, SJ39.1, SJ40.3, SJ43.1, SJ44.3, SJ47.1, SJ48.3, U1.2 (GND), U2.A2 (SGND), U2.D3 (PGND), U5.A2 (SGND), U5.D3 (PGND), U6.2 (GND), U7.A2 (SGND), U7.D3 (PGND), U8.2 (GND), U9.A2 (SGND), U9.D3 (PGND), U10.2 (GND), U13.A2 (SGND), U13.D3 (PGND), U14.2 (GND), U15.A2 (SGND), U15.D3 (PGND), U16.2 (GND), U17.A2 (SGND), U17.D3 (PGND), U18.2 (GND), U21.A2 (SGND), U21.D3 (PGND), U22.2 (GND), U23.A2 (SGND), U23.D3 (PGND), U24.2 (GND), U25.A2 (SGND), U25.D3 (PGND), U26.2 (GND), U29.A2 (SGND), U29.D3 (PGND), U30.2 (GND), U31.A2 (SGND), U31.D3 (PGND), U32.2 (GND), U35.A2 (SGND), U35.D3 (PGND), U36.2 (GND), U39.A2 (SGND), U39.D3 (PGND), U40.2 (GND), U43.A2 (SGND), U43.D3 (PGND), U44.2 (GND), U47.A2 (SGND), U47.D3 (PGND), U48.2 (GND), U$1.1 (GND), U$10.1 (GND), U$17.1 (GND), U$21.1 (GND)
IN+_1: C1.1, JP1.1
IN+_2: C19.1, JP5.1
IN+_3: C37.1, JP9.1
IN+_4: C55.1, JP13.1
IN+_5: C73.1, JP17.1
IN+_6: C91.1, JP21.1
IN+_7: C109.1, JP25.1
IN+_8: C127.1, JP29.1
IN+_9: C28.1, JP7.1
IN+_10: C64.1, JP15.1
IN+_11: C100.1, JP23.1
IN+_12: C136.1, JP31.1
IN+_13: C154.1, JP35.1
IN+_14: C172.1, JP39.1
IN+_15: C190.1, JP43.1
IN+_16: C208.1, JP47.1
IN-_1: C2.1, SJ2.2
IN-_2: C20.1, SJ5.2
IN-_3: C38.1, SJ9.2
IN-_4: C56.1, SJ13.2
IN-_5: C74.1, SJ17.2
IN-_6: C92.1, SJ21.2
IN-_7: C110.1, SJ25.2
IN-_8: C128.1, SJ29.2
IN-_9: C29.1, SJ7.2
IN-_10: C65.1, SJ15.2
IN-_11: C101.1, SJ23.2
IN-_12: C137.1, SJ31.2
IN-_13: C155.1, SJ35.2
IN-_14: C173.1, SJ39.2
IN-_15: C191.1, SJ43.2
IN-_16: C209.1, SJ47.2
unnamed: C1.2, U2.A3 (IN+)
unnamed: C2.2, U2.B3 (IN-)
unnamed: SJ3.2, U2.B2 (GAIN)
unnamed: C7.1, U2.A1 (OUT+)
unnamed: C8.1, U2.B1 (OUT-)
unnamed: C7.2, R1.1, R5.1
unnamed: L1.2, U2.D2 (SW), U$2.2 (A)
unnamed: C9.2, U2.C1 (VAMP), U2.D1 (VBST), U$2.1 (C)
unnamed: C8.2, R2.2, R6.1
unnamed: R3.1, R4.2, U$1.4 (VFB)
unnamed: L3.2, U1.1 (SW)
unnamed: R7.1, R8.2, U1.3 (FB)
unnamed: C15.1, U$1.6 (VBST)
unnamed: C15.2, L2.1, U$1.2 (SW)
unnamed: R11.1, R12.2, U$10.4 (VFB)
unnamed: C49.1, U$10.6 (VBST)
unnamed: C49.2, L11.1, U$10.2 (SW)
unnamed: C19.2, U5.A3 (IN+)
unnamed: C20.2, U5.B3 (IN-)
unnamed: SJ6.2, U5.B2 (GAIN)
unnamed: C23.1, U5.A1 (OUT+)
unnamed: C24.1, U5.B1 (OUT-)
unnamed: C23.2, R13.1, R15.1
unnamed: C24.2, R14.2, R16.1
unnamed: L6.2, U6.1 (SW)
unnamed: R17.1, R18.2, U6.3 (FB)
unnamed: L5.2, U5.D2 (SW), U$3.2 (A)
unnamed: C25.2, U5.C1 (VAMP), U5.D1 (VBST), U$3.1 (C)
unnamed: C28.2, U7.A3 (IN+)
unnamed: C29.2, U7.B3 (IN-)
unnamed: SJ8.2, U7.B2 (GAIN)
unnamed: C32.1, U7.A1 (OUT+)
unnamed: C33.1, U7.B1 (OUT-)
unnamed: C32.2, R19.1, R21.1
unnamed: C33.2, R20.2, R22.1
unnamed: L8.2, U8.1 (SW)
unnamed: R23.1, R24.2, U8.3 (FB)
unnamed: L7.2, U7.D2 (SW), U$4.2 (A)
unnamed: C34.2, U7.C1 (VAMP), U7.D1 (VBST), U$4.1 (C)
unnamed: C37.2, U9.A3 (IN+)
unnamed: C38.2, U9.B3 (IN-)
unnamed: SJ10.2, U9.B2 (GAIN)
unnamed: C41.1, U9.A1 (OUT+)
unnamed: C42.1, U9.B1 (OUT-)
unnamed: C41.2, R25.1, R27.1
unnamed: C42.2, R26.2, R28.1
unnamed: L10.2, U10.1 (SW)
unnamed: R29.1, R30.2, U10.3 (FB)
unnamed: L9.2, U9.D2 (SW), U$5.2 (A)
unnamed: C43.2, U9.C1 (VAMP), U9.D1 (VBST), U$5.1 (C)
unnamed: R33.1, R34.2, U$17.4 (VFB)
unnamed: C86.1, U$17.6 (VBST)
unnamed: C86.2, L19.1, U$17.2 (SW)
unnamed: R55.1, R56.2, U$21.4 (VFB)
unnamed: C123.1, U$21.6 (VBST)
unnamed: C123.2, L27.1, U$21.2 (SW)
unnamed: C55.2, U13.A3 (IN+)
unnamed: C56.2, U13.B3 (IN-)
unnamed: SJ14.2, U13.B2 (GAIN)
unnamed: C59.1, U13.A1 (OUT+)
unnamed: C60.1, U13.B1 (OUT-)
unnamed: C59.2, R37.1, R39.1
unnamed: C60.2, R38.2, R40.1
unnamed: L14.2, U14.1 (SW)
unnamed: R41.1, R42.2, U14.3 (FB)
unnamed: L13.2, U13.D2 (SW), U$7.2 (A)
unnamed: C61.2, U13.C1 (VAMP), U13.D1 (VBST), U$7.1 (C)
unnamed: C64.2, U15.A3 (IN+)
unnamed: C65.2, U15.B3 (IN-)
unnamed: SJ16.2, U15.B2 (GAIN)
unnamed: C68.1, U15.A1 (OUT+)
unnamed: C69.1, U15.B1 (OUT-)
unnamed: C68.2, R43.1, R45.1
unnamed: C69.2, R44.2, R46.1
unnamed: L16.2, U16.1 (SW)
unnamed: R47.1, R48.2, U16.3 (FB)
unnamed: L15.2, U15.D2 (SW), U$8.2 (A)
unnamed: C70.2, U15.C1 (VAMP), U15.D1 (VBST), U$8.1 (C)
unnamed: C73.2, U17.A3 (IN+)
unnamed: C74.2, U17.B3 (IN-)
unnamed: SJ18.2, U17.B2 (GAIN)
unnamed: C77.1, U17.A1 (OUT+)
unnamed: C78.1, U17.B1 (OUT-)
unnamed: C77.2, R49.1, R51.1
unnamed: C78.2, R50.2, R52.1
unnamed: L18.2, U18.1 (SW)
unnamed: R53.1, R54.2, U18.3 (FB)
unnamed: L17.2, U17.D2 (SW), U$9.2 (A)
unnamed: C79.2, U17.C1 (VAMP), U17.D1 (VBST), U$9.1 (C)
unnamed: C91.2, U21.A3 (IN+)
unnamed: C92.2, U21.B3 (IN-)
unnamed: SJ22.2, U21.B2 (GAIN)
unnamed: C95.1, U21.A1 (OUT+)
unnamed: C96.1, U21.B1 (OUT-)
unnamed: C95.2, R61.1, R63.1
unnamed: C96.2, R62.2, R64.1
unnamed: L22.2, U22.1 (SW)
unnamed: R65.1, R66.2, U22.3 (FB)
unnamed: L21.2, U21.D2 (SW), U$11.2 (A)
unnamed: C97.2, U21.C1 (VAMP), U21.D1 (VBST), U$11.1 (C)
unnamed: C100.2, U23.A3 (IN+)
unnamed: C101.2, U23.B3 (IN-)
unnamed: SJ24.2, U23.B2 (GAIN)
unnamed: C104.1, U23.A1 (OUT+)
unnamed: C105.1, U23.B1 (OUT-)
unnamed: C104.2, R67.1, R69.1
unnamed: C105.2, R68.2, R70.1
unnamed: L24.2, U24.1 (SW)
unnamed: R71.1, R72.2, U24.3 (FB)
unnamed: L23.2, U23.D2 (SW), U$12.2 (A)
unnamed: C106.2, U23.C1 (VAMP), U23.D1 (VBST), U$12.1 (C)
unnamed: C109.2, U25.A3 (IN+)
unnamed: C110.2, U25.B3 (IN-)
unnamed: SJ26.2, U25.B2 (GAIN)
unnamed: C113.1, U25.A1 (OUT+)
unnamed: C114.1, U25.B1 (OUT-)
unnamed: C113.2, R73.1, R75.1
unnamed: C114.2, R74.2, R76.1
unnamed: L26.2, U26.1 (SW)
unnamed: R77.1, R78.2, U26.3 (FB)
unnamed: L25.2, U25.D2 (SW), U$13.2 (A)
unnamed: C115.2, U25.C1 (VAMP), U25.D1 (VBST), U$13.1 (C)
unnamed: C127.2, U29.A3 (IN+)
unnamed: C128.2, U29.B3 (IN-)
unnamed: SJ30.2, U29.B2 (GAIN)
unnamed: C131.1, U29.A1 (OUT+)
unnamed: C132.1, U29.B1 (OUT-)
unnamed: C131.2, R85.1, R87.1
unnamed: C132.2, R86.2, R88.1
unnamed: L30.2, U30.1 (SW)
unnamed: R89.1, R90.2, U30.3 (FB)
unnamed: L29.2, U29.D2 (SW), U$15.2 (A)
unnamed: C133.2, U29.C1 (VAMP), U29.D1 (VBST), U$15.1 (C)
unnamed: C136.2, U31.A3 (IN+)
unnamed: C137.2, U31.B3 (IN-)
unnamed: SJ32.2, U31.B2 (GAIN)
unnamed: C140.1, U31.A1 (OUT+)
unnamed: C141.1, U31.B1 (OUT-)
unnamed: C140.2, R91.1, R93.1
unnamed: C141.2, R92.2, R94.1
unnamed: L32.2, U32.1 (SW)
unnamed: R95.1, R96.2, U32.3 (FB)
unnamed: L31.2, U31.D2 (SW), U$16.2 (A)
unnamed: C142.2, U31.C1 (VAMP), U31.D1 (VBST), U$16.1 (C)
unnamed: C154.2, U35.A3 (IN+)
unnamed: C155.2, U35.B3 (IN-)
unnamed: SJ36.2, U35.B2 (GAIN)
unnamed: C158.1, U35.A1 (OUT+)
unnamed: C159.1, U35.B1 (OUT-)
unnamed: C158.2, R103.1, R105.1
unnamed: C159.2, R104.2, R106.1
unnamed: L36.2, U36.1 (SW)
unnamed: R107.1, R108.2, U36.3 (FB)
unnamed: L35.2, U35.D2 (SW), U$18.2 (A)
unnamed: C160.2, U35.C1 (VAMP), U35.D1 (VBST), U$18.1 (C)
unnamed: C172.2, U39.A3 (IN+)
unnamed: C173.2, U39.B3 (IN-)
unnamed: SJ40.2, U39.B2 (GAIN)
unnamed: C176.1, U39.A1 (OUT+)
unnamed: C177.1, U39.B1 (OUT-)
unnamed: C176.2, R115.1, R117.1
unnamed: C177.2, R116.2, R118.1
unnamed: L40.2, U40.1 (SW)
unnamed: R119.1, R120.2, U40.3 (FB)
unnamed: L39.2, U39.D2 (SW), U$20.2 (A)
unnamed: C178.2, U39.C1 (VAMP), U39.D1 (VBST), U$20.1 (C)
unnamed: C190.2, U43.A3 (IN+)
unnamed: C191.2, U43.B3 (IN-)
unnamed: SJ44.2, U43.B2 (GAIN)
unnamed: C194.1, U43.A1 (OUT+)
unnamed: C195.1, U43.B1 (OUT-)
unnamed: C194.2, R127.1, R129.1
unnamed: C195.2, R128.2, R130.1
unnamed: L44.2, U44.1 (SW)
unnamed: R131.1, R132.2, U44.3 (FB)
unnamed: L43.2, U43.D2 (SW), U$22.2 (A)
unnamed: C196.2, U43.C1 (VAMP), U43.D1 (VBST), U$22.1 (C)
unnamed: C208.2, U47.A3 (IN+)
unnamed: C209.2, U47.B3 (IN-)
unnamed: SJ48.2, U47.B2 (GAIN)
unnamed: C212.1, U47.A1 (OUT+)
unnamed: C213.1, U47.B1 (OUT-)
unnamed: C212.2, R139.1, R141.1
unnamed: C213.2, R140.2, R142.1
unnamed: L48.2, U48.1 (SW)
unnamed: R143.1, R144.2, U48.3 (FB)
unnamed: L47.2, U47.D2 (SW), U$24.2 (A)
unnamed: C214.2, U47.C1 (VAMP), U47.D1 (VBST), U$24.1 (C)
OUT+_1: JP2.1, R5.2
OUT+_2: JP6.1, R15.2
OUT+_3: JP10.1, R27.2
OUT+_4: JP14.1, R39.2
OUT+_5: JP18.1, R51.2
OUT+_6: JP22.1, R63.2
OUT+_7: JP26.1, R75.2
OUT+_8: JP30.1, R87.2
OUT+_9: JP8.1, R21.2
OUT+_10: JP16.1, R45.2
OUT+_11: JP24.1, R69.2
OUT+_12: JP32.1, R93.2
OUT+_13: JP36.1, R105.2
OUT+_14: JP40.1, R117.2
OUT+_15: JP44.1, R129.2
OUT+_16: JP48.1, R141.2
OUT-_1: JP2.2, R6.2
OUT-_2: JP6.2, R16.2
OUT-_3: JP10.2, R28.2
OUT-_4: JP14.2, R40.2
OUT-_5: JP18.2, R52.2
OUT-_6: JP22.2, R64.2
OUT-_7: JP26.2, R76.2
OUT-_8: JP30.2, R88.2
OUT-_9: JP8.2, R22.2
OUT-_10: JP16.2, R46.2
OUT-_11: JP24.2, R70.2
OUT-_12: JP32.2, R94.2
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

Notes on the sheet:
Buck converters (3.3V)
Input voltage can be directly connected to 3.3V voltages lines through voltage jumpers
Power amplifier (PA) stages
Input voltage and decoupling
Power amplifier (part of DSP board)

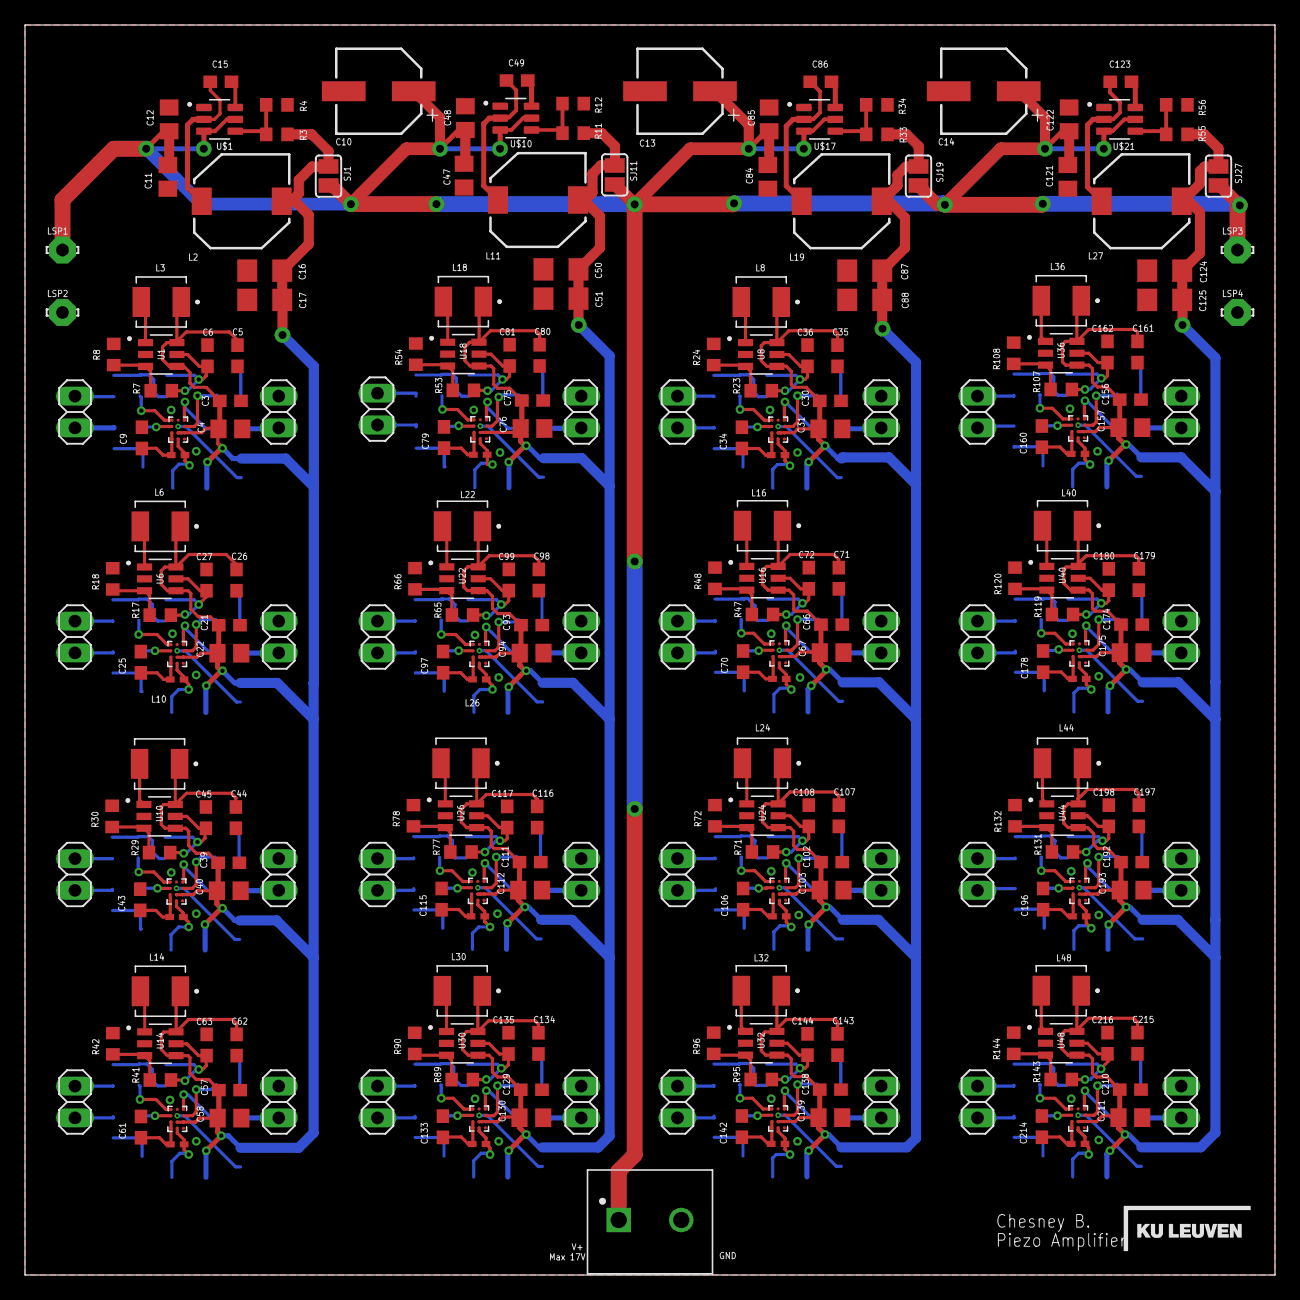
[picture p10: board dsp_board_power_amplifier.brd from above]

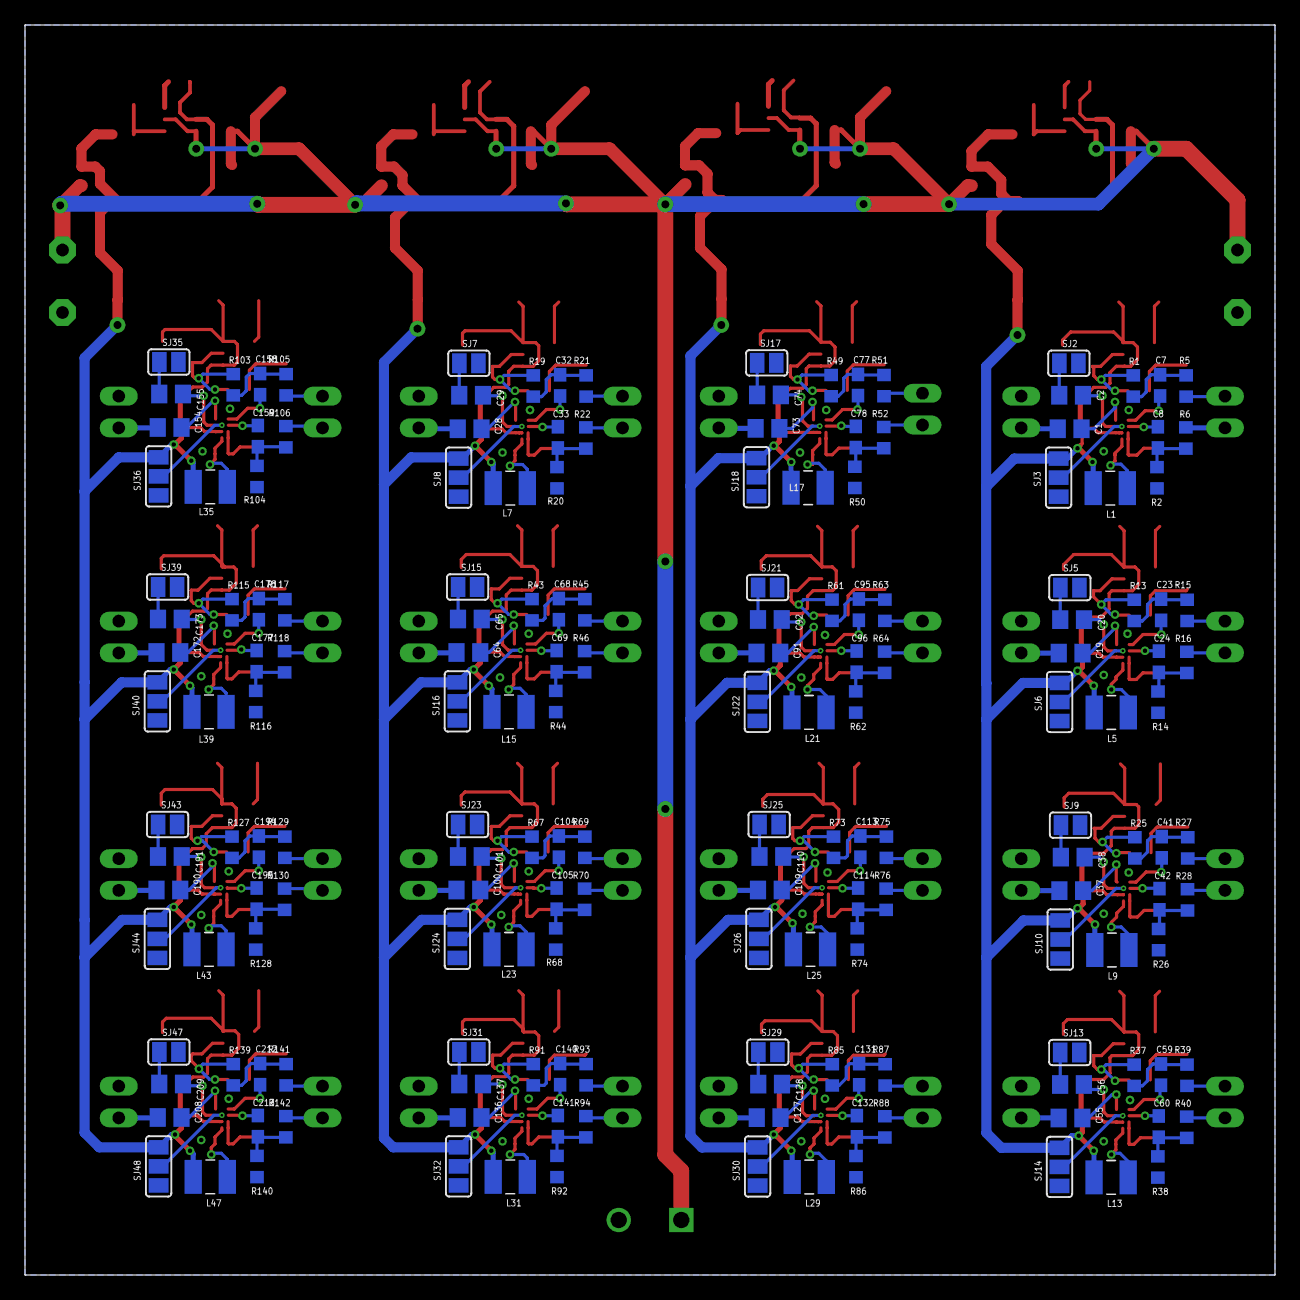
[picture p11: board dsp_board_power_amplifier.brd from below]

Board: 2 copper layers, 100.0 x 100.0 mm, 432 parts (176 on the bottom side), 274 nets.

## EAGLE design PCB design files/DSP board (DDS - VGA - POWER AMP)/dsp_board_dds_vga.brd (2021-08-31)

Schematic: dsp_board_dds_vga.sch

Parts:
C1, C2, C3, C8, C13, C14, C19, C20, C25, C26, C31, C32, C37, C38, C43, C44, C49, C50, C55, C56, C61, C62, C67, C68, C73, C74, C79, C80, C86, C91, C92, C97, C98, C106, C113, C119, C121, C127, C129, C135, C137, C143, C145, C151, C153, C159, C161, C167, C169, C175, C177, C183, C185, C191, C193, C199, C201, C207, C209, C215, C217, C223, C225, C231: 0.1u; C0603
C4, C5, C9, C10, C15, C16, C21, C22, C27, C28, C33, C34, C39, C40, C45, C46, C51, C52, C57, C58, C63, C64, C69, C70, C75, C76, C81, C82, C93, C94, C99, C100: 10n; C0603
C6, C11, C17, C23, C29, C35, C41, C47, C53, C59, C65, C71, C77, C83, C95, C101: 20p; C0603
C7, C12, C18, C24, C30, C36, C42, C48, C54, C60, C66, C72, C78, C84, C96, C102: TBD; C0603
C87, C88, C89, C90, C107, C114, C115, C116, C117, C120, C122, C123, C124, C125, C128, C130, C131, C132, C133, C136, C138, C139, C140, C141, C144, C146, C147, C148, C149, C152, C154, C155, C156, C157, C160, C162, C163, C164, C165, C168, C170, C171, C172, C173, C176, C178, C179, C180, C181, C184, C186, C187, C188, C189, C192, C194, C195, C196, C197, C200, C202, C203, C204, C205, C208, C210, C211, C212, C213, C216, C218, C219, C220, C221, C224, C226, C227, C228, C229, C232: 1u; C0603
C104, C118, C126, C134, C142, C150, C158, C166, C174, C182, C190, C198, C206, C214, C222, C230: 10u; C0805
H1, H2: MOUNT-HOLE3.0; 3,0
IC1, IC2, IC3, IC4, IC5, IC6, IC7, IC8, IC9, IC10, IC11, IC12, IC13, IC14, IC16, IC17: AD9834; TSSOP20
J1, J4: 6130XX21021_61301421021; 61301421021
J2, J7: 6130XX21021_61301621021; 61301621021
JP1, JP2, JP3, JP4, JP5, JP6, JP7, JP8, JP9, JP10, JP11, JP12, JP13, JP14, JP15, JP16: PINHD-1X2; 1X02
LDO, LDO2, LDO3, LDO4, LDO5, LDO6, LDO7, LDO8, LDO9, LDO10, LDO11, LDO12, LDO13, LDO14, LDO15, LDO16: TLV75525PDBVR; SOT95P280X145-5N
LSP1, LSP2, LSP3, LSP4, LSP5, LSP6, LSP7, LSP8, LSP9, LSP10, LSP11, LSP12, LSP13, LSP14, LSP15, LSP16, LSP17, LSP18, LSP19, LSP20: LSP10
R1, R2, R9, R13, R17, R21, R25, R29, R33, R37, R41, R45, R49, R53, R61, R65: 6.8k; R0603
R3, R8, R12, R16, R20, R24, R28, R32, R36, R40, R44, R48, R52, R56, R64, R68: TBD; R0603
R4, R5, R6, R7, R10, R11, R14, R15, R18, R19, R22, R23, R26, R27, R30, R31, R34, R35, R38, R39, R42, R43, R46, R47, R50, R51, R54, R55, R62, R63, R66, R67: 200; R0603
R57, R59, R60, R69, R70, R71, R72, R73, R74, R75, R76, R77, R78, R79, R80, R81: R-EU_R0603; R0603
SJ1, SJ2, SJ3, SJ4, SJ5, SJ6, SJ7, SJ8, SJ9, SJ10, SJ11, SJ12, SJ13, SJ14, SJ15, SJ16, SJ17, SJ18, SJ19, SJ20, SJ21, SJ22, SJ23, SJ24, SJ25, SJ26, SJ27, SJ28, SJ29, SJ30, SJ31, SJ32, SJ33, SJ34, SJ35, SJ36, SJ37, SJ38, SJ39, SJ40, SJ41, SJ42, SJ43, SJ44, SJ45, SJ46, SJ47, SJ48, SJ49, SJ50, SJ51, SJ52, SJ53, SJ54, SJ55, SJ56, SJ57, SJ58, SJ59, SJ60, SJ61, SJ62, SJ63, SJ64, SJ65, SJ66, SJ67, SJ68, SJ69, SJ70, SJ71, SJ72, SJ73, SJ74, SJ75, SJ76, SJ77, SJ78, SJ79, SJ80, SJ81, SJ82, SJ83, SJ84, SJ91, SJ92, SJ93, SJ94, SJ95, SJ96, SJ97, SJ98, SJ99, SJ100, SJ101, SJ102: SJ
U1, U7, U10, U13, U16, U19, U22, U25, U28, U31, U34, U37, U40, U43, U46, U49: TPS60400DBVT; SOT95P280X145-5N
U2, U9, U12, U15, U18, U21, U24, U27, U30, U33, U36, U39, U42, U45, U48, U51: TLV271CDBVR; SOT95P280X145-5N
U3, U8, U11, U14, U17, U20, U23, U26, U29, U32, U35, U38, U41, U44, U47, U50: AD5270BRMZ-50; SOP50P490X110-10N

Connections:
2.5V_1: C86.2, C89.2, C104.1, LDO.5 (OUT), U1.2 (IN), U2.5 (VDD), U3.1 (VDD)
2.5V_2: C113.2, C116.2, C118.1, LDO2.5 (OUT), U7.2 (IN), U8.1 (VDD), U9.5 (VDD)
2.5V_3: C137.2, C140.2, C142.1, LDO5.5 (OUT), U16.2 (IN), U17.1 (VDD), U18.5 (VDD)
2.5V_4: C145.2, C148.2, C150.1, LDO6.5 (OUT), U19.2 (IN), U20.1 (VDD), U21.5 (VDD)
2.5V_5: C121.2, C124.2, C126.1, LDO3.5 (OUT), U10.2 (IN), U11.1 (VDD), U12.5 (VDD)
2.5V_6: C129.2, C132.2, C134.1, LDO4.5 (OUT), U13.2 (IN), U14.1 (VDD), U15.5 (VDD)
2.5V_7: C153.2, C156.2, C158.1, LDO7.5 (OUT), U22.2 (IN), U23.1 (VDD), U24.5 (VDD)
2.5V_8: C161.2, C164.2, C166.1, LDO8.5 (OUT), U25.2 (IN), U26.1 (VDD), U27.5 (VDD)
2.5V_9: C169.2, C172.2, C174.1, LDO9.5 (OUT), U28.2 (IN), U29.1 (VDD), U30.5 (VDD)
2.5V_10: C177.2, C180.2, C182.1, LDO10.5 (OUT), U31.2 (IN), U32.1 (VDD), U33.5 (VDD)
2.5V_11: C201.2, C204.2, C206.1, LDO13.5 (OUT), U40.2 (IN), U41.1 (VDD), U42.5 (VDD)
2.5V_12: C209.2, C212.2, C214.1, LDO14.5 (OUT), U43.2 (IN), U44.1 (VDD), U45.5 (VDD)
2.5V_13: C185.2, C188.2, C190.1, LDO11.5 (OUT), U34.2 (IN), U35.1 (VDD), U36.5 (VDD)
2.5V_14: C193.2, C196.2, C198.1, LDO12.5 (OUT), U37.2 (IN), U38.1 (VDD), U39.5 (VDD)
2.5V_15: C217.2, C220.2, C222.1, LDO15.5 (OUT), U46.2 (IN), U47.1 (VDD), U48.5 (VDD)
2.5V_16: C225.2, C228.2, C230.1, LDO16.5 (OUT), U49.2 (IN), U50.1 (VDD), U51.5 (VDD)
+3V3: C1.1, C2.1, C5.2, C10.2, C13.1, C16.2, C19.1, C22.2, C25.1, C28.2, C31.1, C34.2, C37.1, C40.2, C43.1, C46.2, C49.1, C52.2, C55.1, C58.2, C61.1, C64.2, C67.1, C70.2, C73.1, C76.2, C79.1, C82.2, C87.2, C91.1, C94.2, C97.1, C100.2, C114.2, C122.2, C130.2, C138.2, C146.2, C154.2, C162.2, C170.2, C178.2, C186.2, C194.2, C202.2, C210.2, C218.2, C226.2, IC1.4 (AVDD), IC1.5 (DVDD), IC2.4 (AVDD), IC2.5 (DVDD), IC3.4 (AVDD), IC3.5 (DVDD), IC4.4 (AVDD), IC4.5 (DVDD), IC5.4 (AVDD), IC5.5 (DVDD), IC6.4 (AVDD), IC6.5 (DVDD), IC7.4 (AVDD), IC7.5 (DVDD), IC8.4 (AVDD), IC8.5 (DVDD), IC9.4 (AVDD), IC9.5 (DVDD), IC10.4 (AVDD), IC10.5 (DVDD), IC11.4 (AVDD), IC11.5 (DVDD), IC12.4 (AVDD), IC12.5 (DVDD), IC13.4 (AVDD), IC13.5 (DVDD), IC14.4 (AVDD), IC14.5 (DVDD), IC16.4 (AVDD), IC16.5 (DVDD), IC17.4 (AVDD), IC17.5 (DVDD), J2.1, J7.1, LDO.1 (IN), LDO.3 (EN), LDO2.1 (IN), LDO2.3 (EN), LDO3.1 (IN), LDO3.3 (EN), LDO4.1 (IN), LDO4.3 (EN), LDO5.1 (IN), LDO5.3 (EN), LDO6.1 (IN), LDO6.3 (EN), LDO7.1 (IN), LDO7.3 (EN), LDO8.1 (IN), LDO8.3 (EN), LDO9.1 (IN), LDO9.3 (EN), LDO10.1 (IN), LDO10.3 (EN), LDO11.1 (IN), LDO11.3 (EN), LDO12.1 (IN), LDO12.3 (EN), LDO13.1 (IN), LDO13.3 (EN), LDO14.1 (IN), LDO14.3 (EN), LDO15.1 (IN), LDO15.3 (EN), LDO16.1 (IN), LDO16.3 (EN)
DDS1_OUT: R57.1, SJ1.2, SJ2.2
DDS2_OUT: R59.1, SJ6.2, SJ8.2
DDS3_OUT: R70.1, SJ13.2, SJ14.2
DDS4_OUT: R71.1, SJ19.2, SJ20.2
DDS5_OUT: R60.1, SJ25.2, SJ26.2
DDS6_OUT: R69.1, SJ31.2, SJ32.2
DDS7_OUT: R72.1, SJ37.2, SJ38.2
DDS8_OUT: R73.1, SJ43.2, SJ44.2
DDS9_OUT: R74.1, SJ49.2, SJ50.2
DDS10_OUT: R75.1, SJ55.2, SJ56.2
DDS11_OUT: R78.1, SJ61.2, SJ62.2
DDS12_OUT: R79.1, SJ67.2, SJ68.2
DDS13_OUT: R76.1, SJ73.2, SJ74.2
DDS14_OUT: R77.1, SJ91.2, SJ92.2
DDS15_OUT: R80.1, SJ79.2, SJ80.2
DDS16_OUT: R81.1, SJ97.2, SJ98.2
DIN_2_A: J2.12, U3.8 (DIN), U8.8 (DIN), U17.8 (DIN), U20.8 (DIN)
DIN_2_B: J4.10, U11.8 (DIN), U14.8 (DIN), U23.8 (DIN), U26.8 (DIN)
DIN_2_C: J1.10, U29.8 (DIN), U32.8 (DIN), U41.8 (DIN), U44.8 (DIN)
DIN_2_D: J7.12, U35.8 (DIN), U38.8 (DIN), U47.8 (DIN), U50.8 (DIN)
FILTER1: C7.1, R3.2, SJ1.1, SJ4.2, SJ5.2
FILTER2: C12.1, R8.2, SJ6.1, SJ11.2, SJ12.2
FILTER3: C18.1, R12.2, SJ13.1, SJ17.2, SJ18.2
FILTER4: C24.1, R16.2, SJ19.1, SJ23.2, SJ24.2
FILTER5: C30.1, R20.2, SJ25.1, SJ29.2, SJ30.2
FILTER6: C36.1, R24.2, SJ31.1, SJ35.2, SJ36.2
FILTER7: C42.1, R28.2, SJ37.1, SJ41.2, SJ42.2
FILTER8: C48.1, R32.2, SJ43.1, SJ47.2, SJ48.2
FILTER9: C54.1, R36.2, SJ49.1, SJ53.2, SJ54.2
FILTER10: C60.1, R40.2, SJ55.1, SJ59.2, SJ60.2
FILTER11: C66.1, R44.2, SJ61.1, SJ65.2, SJ66.2
FILTER12: C72.1, R48.2, SJ67.1, SJ71.2, SJ72.2
FILTER13: C78.1, R52.2, SJ73.1, SJ77.2, SJ78.2
FILTER14: C96.1, R64.2, SJ91.1, SJ95.2, SJ96.2
FILTER15: C84.1, R56.2, SJ79.1, SJ83.2, SJ84.2
FILTER16: C102.1, R68.2, SJ97.1, SJ101.2, SJ102.2
FSELECT_A: IC1.9 (FSELECT), IC2.9 (FSELECT), IC3.9 (FSELECT), IC4.9 (FSELECT), J2.3
FSELECT_B: IC5.9 (FSELECT), IC6.9 (FSELECT), IC7.9 (FSELECT), IC8.9 (FSELECT), J4.1
FSELECT_C: IC9.9 (FSELECT), IC10.9 (FSELECT), IC11.9 (FSELECT), IC12.9 (FSELECT), J1.1
FSELECT_D: IC13.9 (FSELECT), IC14.9 (FSELECT), IC16.9 (FSELECT), IC17.9 (FSELECT), J7.3
FSYNC1: IC1.15 (FSYNC), J2.5, U3.10 (~SYNC)
FSYNC2: IC2.15 (FSYNC), J2.8, U8.10 (~SYNC)
FSYNC3: IC3.15 (FSYNC), J2.7, U17.10 (~SYNC)
FSYNC4: IC4.15 (FSYNC), J2.10, U20.10 (~SYNC)
FSYNC5: IC5.15 (FSYNC), J4.3, U11.10 (~SYNC)
FSYNC6: IC6.15 (FSYNC), J4.6, U14.10 (~SYNC)
FSYNC7: IC7.15 (FSYNC), J4.5, U23.10 (~SYNC)
FSYNC8: IC8.15 (FSYNC), J4.8, U26.10 (~SYNC)
FSYNC9: IC9.15 (FSYNC), J1.3, U29.10 (~SYNC)
FSYNC10: IC10.15 (FSYNC), J1.6, U32.10 (~SYNC)
FSYNC11: IC11.15 (FSYNC), J1.5, U41.10 (~SYNC)
FSYNC12: IC12.15 (FSYNC), J1.8, U44.10 (~SYNC)
FSYNC13: IC13.15 (FSYNC), J7.5, U35.10 (~SYNC)
FSYNC14: IC16.15 (FSYNC), J7.8, U38.10 (~SYNC)
FSYNC15: IC14.15 (FSYNC), J7.7, U47.10 (~SYNC)
FSYNC16: IC17.15 (FSYNC), J7.10, U50.10 (~SYNC)
GND: C1.2, C2.2, C3.2, C4.2, C6.2, C7.2, C8.2, C9.2, C11.2, C12.2, C13.2, C14.2, C15.2, C17.2, C18.2, C19.2, C20.2, C21.2, C23.2, C24.2, C25.2, C26.2, C27.2, C29.2, C30.2, C31.2, C32.2, C33.2, C35.2, C36.2, C37.2, C38.2, C39.2, C41.2, C42.2, C43.2, C44.2, C45.2, C47.2, C48.2, C49.2, C50.2, C51.2, C53.2, C54.2, C55.2, C56.2, C57.2, C59.2, C60.2, C61.2, C62.2, C63.2, C65.2, C66.2, C67.2, C68.2, C69.2, C71.2, C72.2, C73.2, C74.2, C75.2, C77.2, C78.2, C79.2, C80.2, C81.2, C83.2, C84.2, C86.1, C87.1, C89.1, C90.1, C91.2, C92.2, C93.2, C95.2, C96.2, C97.2, C98.2, C99.2, C101.2, C102.2, C104.2, C106.2, C107.2, C113.1, C114.1, C116.1, C117.1, C118.2, C119.2, C120.2, C121.1, C122.1, C124.1, C125.1, C126.2, C127.2, C128.2, C129.1, C130.1, C132.1, C133.1, C134.2, C135.2, C136.2, C137.1, C138.1, C140.1, C141.1, C142.2, C143.2, C144.2, C145.1, C146.1, C148.1, C149.1, C150.2, C151.2, C152.2, C153.1, C154.1, C156.1, C157.1, C158.2, C159.2, C160.2, C161.1, C162.1, C164.1, C165.1, C166.2, C167.2, C168.2, C169.1, C170.1, C172.1, C173.1, C174.2, C175.2, C176.2, C177.1, C178.1, C180.1, C181.1, C182.2, C183.2, C184.2, C185.1, C186.1, C188.1, C189.1, C190.2, C191.2, C192.2, C193.1, C194.1, C196.1, C197.1, C198.2, C199.2, C200.2, C201.1, C202.1, C204.1, C205.1, C206.2, C207.2, C208.2, C209.1, C210.1, C212.1, C213.1, C214.2, C215.2, C216.2, C217.1, C218.1, C220.1, C221.1, C222.2, C223.2, C224.2, C225.1, C226.1, C228.1, C229.1, C230.2, C231.2, C232.2, IC1.7 (DGND), IC1.18 (AGND), IC2.7 (DGND), IC2.18 (AGND), IC3.7 (DGND), IC3.18 (AGND), IC4.7 (DGND), IC4.18 (AGND), IC5.7 (DGND), IC5.18 (AGND), IC6.7 (DGND), IC6.18 (AGND), IC7.7 (DGND), IC7.18 (AGND), IC8.7 (DGND), IC8.18 (AGND), IC9.7 (DGND), IC9.18 (AGND), IC10.7 (DGND), IC10.18 (AGND), IC11.7 (DGND), IC11.18 (AGND), IC12.7 (DGND), IC12.18 (AGND), IC13.7 (DGND), IC13.18 (AGND), IC14.7 (DGND), IC14.18 (AGND), IC16.7 (DGND), IC16.18 (AGND), IC17.7 (DGND), IC17.18 (AGND), J2.2, J7.2, JP1.2, JP2.2, JP3.2, JP4.2, JP5.2, JP6.2, JP7.2, JP8.2, JP9.2, JP10.2, JP11.2, JP12.2, JP13.2, JP14.2, JP15.2, JP16.2, LDO.2 (GND), LDO2.2 (GND), LDO3.2 (GND), LDO4.2 (GND), LDO5.2 (GND), LDO6.2 (GND), LDO7.2 (GND), LDO8.2 (GND), LDO9.2 (GND), LDO10.2 (GND), LDO11.2 (GND), LDO12.2 (GND), LDO13.2 (GND), LDO14.2 (GND), LDO15.2 (GND), LDO16.2 (GND), LSP1.MP, LSP2.MP, LSP3.MP, LSP4.MP, LSP5.MP, LSP6.MP, LSP7.MP, LSP8.MP, LSP9.MP, LSP10.MP, LSP11.MP, LSP12.MP, LSP13.MP, LSP14.MP, LSP15.MP, LSP16.MP, LSP17.MP, LSP18.MP, LSP19.MP, LSP20.MP, R1.2, R2.2, R4.1, R5.1, R6.1, R7.1, R9.2, R10.1, R11.1, R13.2, R14.1, R15.1, R17.2, R18.1, R19.1, R21.2, R22.1, R23.1, R25.2, R26.1, R27.1, R29.2, R30.1, R31.1, R33.2, R34.1, R35.1, R37.2, R38.1, R39.1, R41.2, R42.1, R43.1, R45.2, R46.1, R47.1, R49.2, R50.1, R51.1, R53.2, R54.1, R55.1, R61.2, R62.1, R63.1, R65.2, R66.1, R67.1, SJ3.1, SJ7.2, SJ9.1, SJ10.2, SJ15.1, SJ16.2, SJ21.1, SJ22.2, SJ27.1, SJ28.2, SJ33.1, SJ34.2, SJ39.1, SJ40.2, SJ45.1, SJ46.2, SJ51.1, SJ52.2, SJ57.1, SJ58.2, SJ63.1, SJ64.2, SJ69.1, SJ70.2, SJ75.1, SJ76.2, SJ81.1, SJ82.2, SJ93.1, SJ94.2, SJ99.1, SJ100.2, U1.4 (GND), U2.3 (IN+), U3.6 (GND), U7.4 (GND), U8.6 (GND), U9.3 (IN+), U10.4 (GND), U11.6 (GND), U12.3 (IN+), U13.4 (GND), U14.6 (GND), U15.3 (IN+), U16.4 (GND), U17.6 (GND), U18.3 (IN+), U19.4 (GND), U20.6 (GND), U21.3 (IN+), U22.4 (GND), U23.6 (GND), U24.3 (IN+), U25.4 (GND), U26.6 (GND), U27.3 (IN+), U28.4 (GND), U29.6 (GND), U30.3 (IN+), U31.4 (GND), U32.6 (GND), U33.3 (IN+), U34.4 (GND), U35.6 (GND), U36.3 (IN+), U37.4 (GND), U38.6 (GND), U39.3 (IN+), U40.4 (GND), U41.6 (GND), U42.3 (IN+), U43.4 (GND), U44.6 (GND), U45.3 (IN+), U46.4 (GND), U47.6 (GND), U48.3 (IN+), U49.4 (GND), U50.6 (GND), U51.3 (IN+)
IOUT1: IC1.19 (IOUT), R3.1, R5.2, SJ4.1
IOUT2: IC2.19 (IOUT), R7.2, R8.1, SJ11.1
IOUT3: IC3.19 (IOUT), R11.2, R12.1, SJ17.1
IOUT4: IC4.19 (IOUT), R15.2, R16.1, SJ23.1
IOUT5: IC5.19 (IOUT), R19.2, R20.1, SJ29.1
IOUT6: IC6.19 (IOUT), R23.2, R24.1, SJ35.1
IOUT7: IC7.19 (IOUT), R27.2, R28.1, SJ41.1
IOUT8: IC8.19 (IOUT), R31.2, R32.1, SJ47.1
IOUT9: IC9.19 (IOUT), R35.2, R36.1, SJ53.1
IOUT10: IC10.19 (IOUT), R39.2, R40.1, SJ59.1
IOUT11: IC11.19 (IOUT), R43.2, R44.1, SJ65.1
IOUT12: IC12.19 (IOUT), R47.2, R48.1, SJ71.1
IOUT13: IC13.19 (IOUT), R51.2, R52.1, SJ77.1
IOUT14: IC16.19 (IOUT), R63.2, R64.1, SJ95.1
IOUT15: IC14.19 (IOUT), R55.2, R56.1, SJ83.1
IOUT16: IC17.19 (IOUT), R67.2, R68.1, SJ101.1
IOUTB1: C6.1, IC1.20 (IOUTB), R4.2, SJ7.1
IOUTB2: C11.1, IC2.20 (IOUTB), R6.2, SJ10.1
IOUTB3: C17.1, IC3.20 (IOUTB), R10.2, SJ16.1
IOUTB4: C23.1, IC4.20 (IOUTB), R14.2, SJ22.1
IOUTB5: C29.1, IC5.20 (IOUTB), R18.2, SJ28.1
IOUTB6: C35.1, IC6.20 (IOUTB), R22.2, SJ34.1
IOUTB7: C41.1, IC7.20 (IOUTB), R26.2, SJ40.1
IOUTB8: C47.1, IC8.20 (IOUTB), R30.2, SJ46.1
IOUTB9: C53.1, IC9.20 (IOUTB), R34.2, SJ52.1
IOUTB10: C59.1, IC10.20 (IOUTB), R38.2, SJ58.1
IOUTB11: C65.1, IC11.20 (IOUTB), R42.2, SJ64.1
IOUTB12: C71.1, IC12.20 (IOUTB), R46.2, SJ70.1
IOUTB13: C77.1, IC13.20 (IOUTB), R50.2, SJ76.1
IOUTB14: C95.1, IC16.20 (IOUTB), R62.2, SJ94.1
IOUTB15: C83.1, IC14.20 (IOUTB), R54.2, SJ82.1
IOUTB16: C101.1, IC17.20 (IOUTB), R66.2, SJ100.1
MCLK_A: IC1.8 (MCLK), IC2.8 (MCLK), IC3.8 (MCLK), IC4.8 (MCLK), J2.6
MCLK_B: IC5.8 (MCLK), IC6.8 (MCLK), IC7.8 (MCLK), IC8.8 (MCLK), J4.4
MCLK_C: IC9.8 (MCLK), IC10.8 (MCLK), IC11.8 (MCLK), IC12.8 (MCLK), J1.4
MCLK_D: IC13.8 (MCLK), IC14.8 (MCLK), IC16.8 (MCLK), IC17.8 (MCLK), J7.6
unnamed: C3.1, IC1.6 (CAP/2,5V)
unnamed: IC1.1 (FS_ADJUST), R1.1
unnamed: C4.1, IC1.2 (REFOUT)
unnamed: C5.1, IC1.3 (COMP)
unnamed: IC1.17 (VIN), SJ3.2, SJ5.1
unnamed: C8.1, IC2.6 (CAP/2,5V)
unnamed: IC2.1 (FS_ADJUST), R2.1
unnamed: C9.1, IC2.2 (REFOUT)
unnamed: C10.1, IC2.3 (COMP)
unnamed: IC2.17 (VIN), SJ9.2, SJ12.1
unnamed: C14.1, IC3.6 (CAP/2,5V)
unnamed: IC3.1 (FS_ADJUST), R9.1
unnamed: C15.1, IC3.2 (REFOUT)
unnamed: C16.1, IC3.3 (COMP)
unnamed: IC3.17 (VIN), SJ15.2, SJ18.1
unnamed: C20.1, IC4.6 (CAP/2,5V)
unnamed: IC4.1 (FS_ADJUST), R13.1
unnamed: C21.1, IC4.2 (REFOUT)
unnamed: C22.1, IC4.3 (COMP)
unnamed: IC4.17 (VIN), SJ21.2, SJ24.1
unnamed: C26.1, IC5.6 (CAP/2,5V)
unnamed: IC5.1 (FS_ADJUST), R17.1
unnamed: C27.1, IC5.2 (REFOUT)
unnamed: C28.1, IC5.3 (COMP)
unnamed: IC5.17 (VIN), SJ27.2, SJ30.1
unnamed: C32.1, IC6.6 (CAP/2,5V)
unnamed: IC6.1 (FS_ADJUST), R21.1
unnamed: C33.1, IC6.2 (REFOUT)
unnamed: C34.1, IC6.3 (COMP)
unnamed: IC6.17 (VIN), SJ33.2, SJ36.1
unnamed: C38.1, IC7.6 (CAP/2,5V)
unnamed: IC7.1 (FS_ADJUST), R25.1
unnamed: C39.1, IC7.2 (REFOUT)
unnamed: C40.1, IC7.3 (COMP)
unnamed: IC7.17 (VIN), SJ39.2, SJ42.1
unnamed: C44.1, IC8.6 (CAP/2,5V)
unnamed: IC8.1 (FS_ADJUST), R29.1
unnamed: C45.1, IC8.2 (REFOUT)
unnamed: C46.1, IC8.3 (COMP)
unnamed: IC8.17 (VIN), SJ45.2, SJ48.1
unnamed: C50.1, IC9.6 (CAP/2,5V)
unnamed: IC9.1 (FS_ADJUST), R33.1
unnamed: C51.1, IC9.2 (REFOUT)
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

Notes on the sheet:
Direct Digital Synthesizer (DDS) stages
Variable Gain Amplifier (VGA) stages
Connections to signal distribution board (part of controller board)
Digital Signal Processing (DSP) board

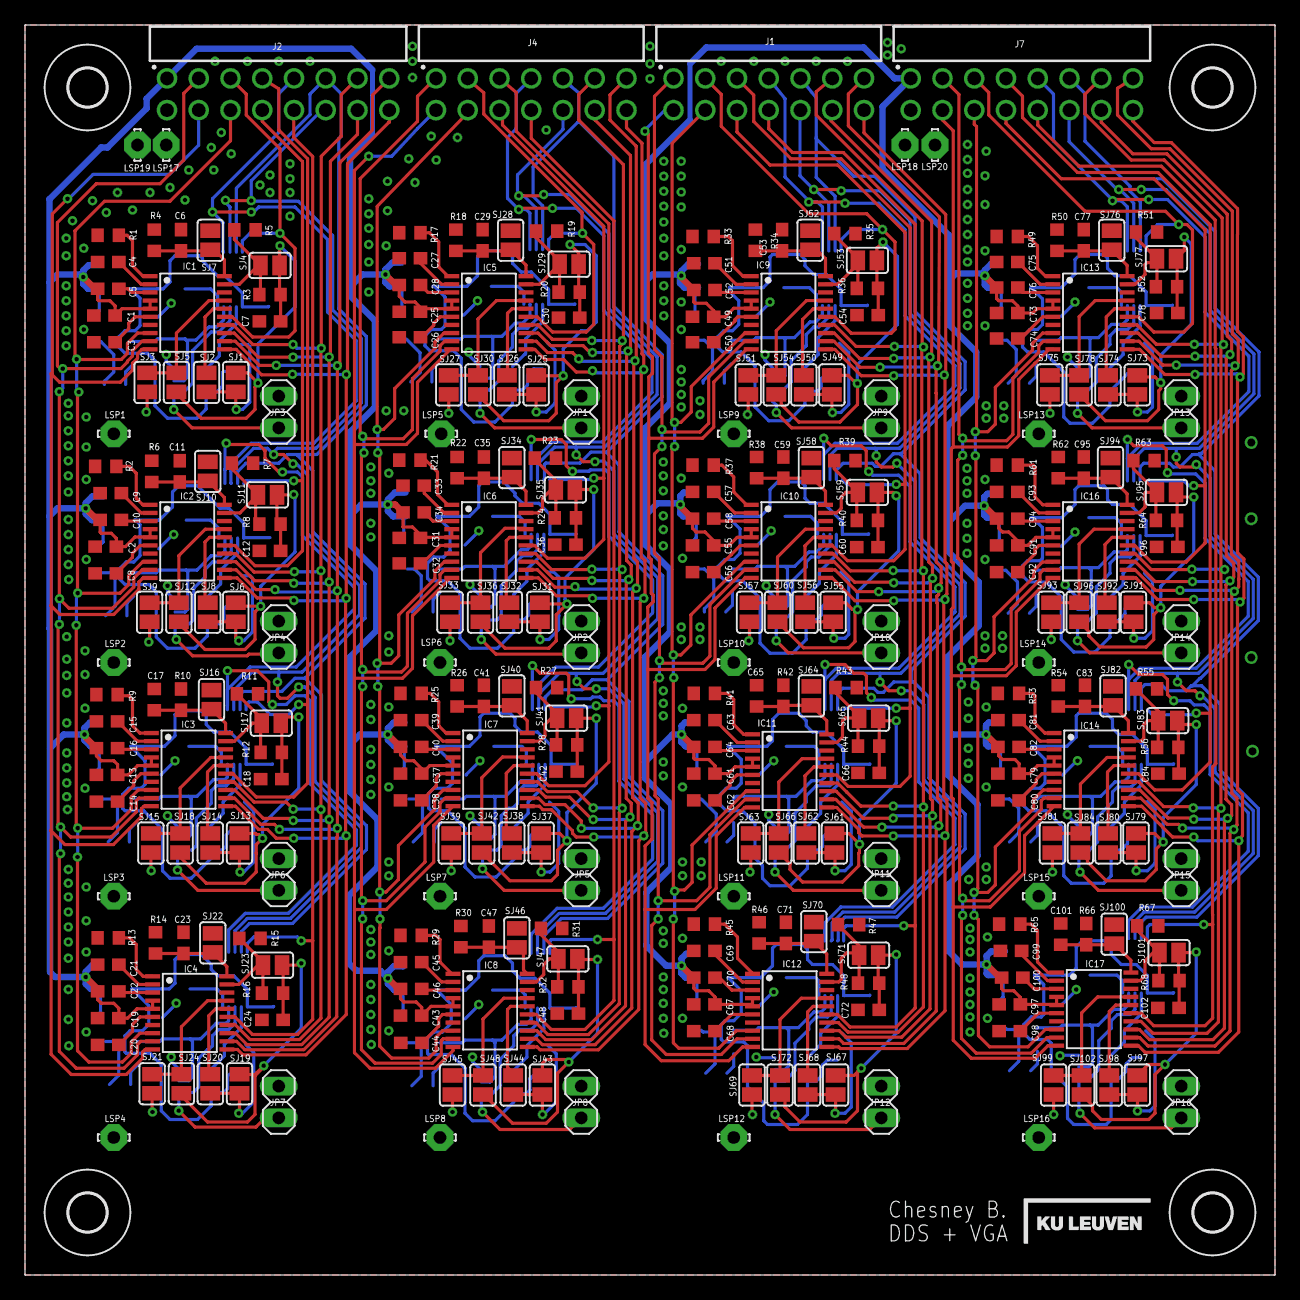
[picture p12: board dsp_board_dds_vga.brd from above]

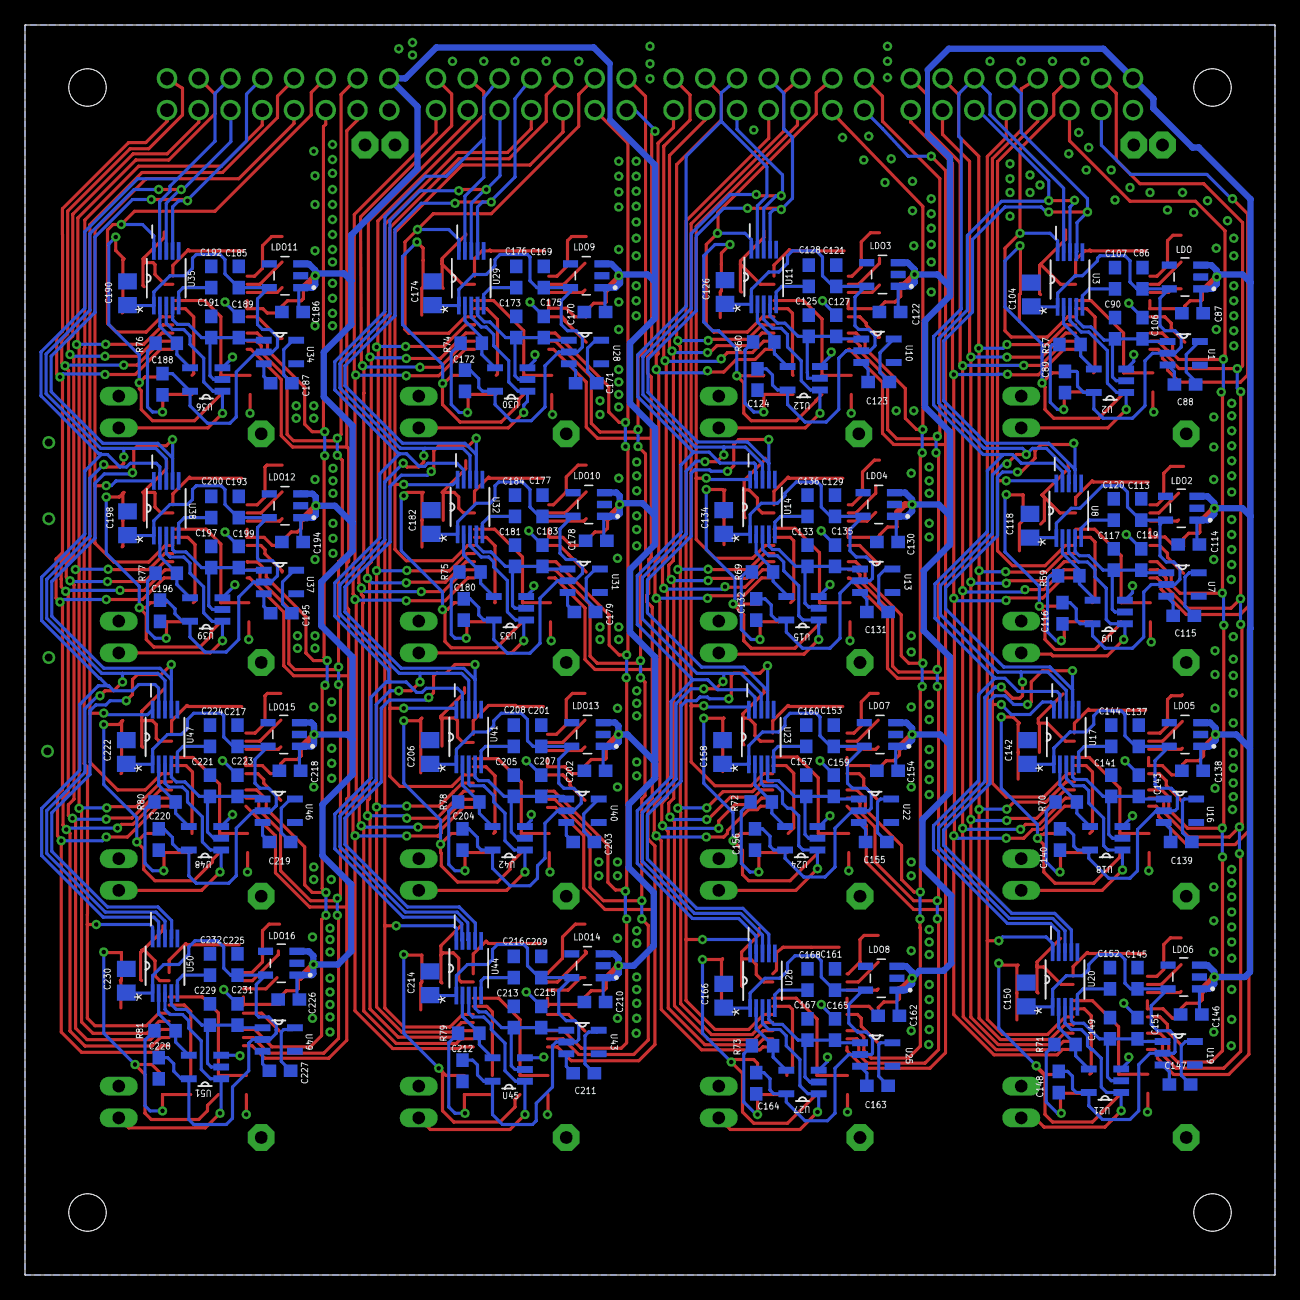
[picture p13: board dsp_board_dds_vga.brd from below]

Board: 2 copper layers, 100.0 x 100.0 mm, 524 parts (208 on the bottom side), 330 nets.

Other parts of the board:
H3, H4: MOUNT-HOLE3.0; 3,0

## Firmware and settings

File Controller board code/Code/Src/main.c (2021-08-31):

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

/* Includes ------------------------------------------------------------------*/
#include "main.h"
#include "spi.h"
#include "tim.h"
#include "usart.h"
#include "usb_device.h"
#include "gpio.h"

/* USER CODE BEGIN Includes */

#include "AD9834.h"
#include "AD5270_71.h"
#include "mux.h"
//#include "matrix.h"
#include "defines.h"
#include "usbd_cdc_if.h"

/* USER CODE END Includes */


/* USER CODE BEGIN PV */

extern TIM_HandleTypeDef htim4;

/* USER CODE END PV */

void SystemClock_Config(void);
/**
  * @brief  The application entry point.
  * @retval int
  */
int main(void)
{
  /* MCU Configuration--------------------------------------------------------*/

  /* Reset of all peripherals, Initializes the Flash interface and the Systick. */
  HAL_Init();

  /* Configure the system clock */
  SystemClock_Config();

  /* Initialize all configured peripherals */
  MX_GPIO_Init();
  MX_SPI1_Init();
  MX_SPI3_Init();
  MX_SPI4_Init();
  MX_SPI5_Init();
  MX_USART3_UART_Init();
  MX_USB_DEVICE_Init();
  MX_TIM4_Init();
  /* USER CODE BEGIN 2 */
	
	uint8_t devices[NUM_DEVICES] = {0x03, 0x0B, 0x01, 0x09, 0x07, 0x05, 0x0F, 0x0D, 0x00, 0x02};
	
	mux_init();
	AD9834_global_init(devices);
	AD5270_71_global_init(devices);

	// Enable timer to generate clock signal (Master clock DDS)
	HAL_TIM_Base_Start(&htim4);
	HAL_TIM_PWM_Start(&htim4, TIM_CHANNEL_3);
	
	//AD9834_init();
	//AD5270_71_init();
	
	// matrix_init();

	
  /* USER CODE END 2 */

  /* Infinite loop */
  /* USER CODE BEGIN WHILE */
	
	write_RDAC(0x0D, 15000);
	write_RDAC(0x0F, 15000);
	write_RDAC(0x05, 15000);
	write_RDAC(0x07, 15000);
	write_RDAC(0x09, 15000);
	write_RDAC(0x0B, 15000);
	write_RDAC(0x01, 15000);
	write_RDAC(0x03, 15000);
	write_RDAC(0x00, 15000);
	write_RDAC(0x02, 15000);
	
  while (1)
  {
		uint8_t dataBuffer[PAYLOAD_SIZE];
		
		uint8_t numBytesReceived = 0;
		uint8_t ch;
		
		while (numBytesReceived < PAYLOAD_SIZE){
			// Read bytes one by one from the receive ring buffer
			if (CDC_Read_FS(&ch, 1) == 0){
				dataBuffer[numBytesReceived++] = ch;
			}
		}
		
		// 
		uint8_t command = dataBuffer[COMMAND_PAYLOAD_OFFSET];
		
		switch(command){
			
			// Change settings specific speaker element
			case CHANGE_SPEAKER_SETTING:
			{
				uint8_t dev = dataBuffer[DEV_PAYLOAD_OFFSET];
				uint16_t frequency = dataBuffer[FREQ_MSB_PAYLOAD_OFFSET] << 8 | dataBuffer[FREQ_LSB_PAYLOAD_OFFSET];
				uint16_t phase = dataBuffer[PHASE_MSB_PAYLOAD_OFFSET] << 8 | dataBuffer[PHASE_LSB_PAYLOAD_OFFSET];
				uint16_t amplitude = dataBuffer[AMP_MSB_PAYLOAD_OFFSET] << 8 | dataBuffer[AMP_LSB_PAYLOAD_OFFSET];
					
				AD9834_set(dev, 0, frequency, phase);
				write_RDAC(dev, amplitude);
				
				// Send 'OK' if command is received
				uint8_t resp[11];
				sprintf(resp, "OK DEV(%d)\n", dev);
				CDC_Transmit_FS(resp, sizeof(resp));
			}
				break;
			
			// Disable (sleep) specific speaker element
			case DISABLE_SPEAKER:
			{
				uint8_t dev = dataBuffer[DEV_PAYLOAD_OFFSET];
				AD9834_disable(dev);
			}
				break;
			case CHANGE_SPEAKER_VGA:
			{
				uint8_t dev = dataBuffer[DEV_PAYLOAD_OFFSET];
				uint16_t frequency = dataBuffer[FREQ_MSB_PAYLOAD_OFFSET] << 8 | dataBuffer[FREQ_LSB_PAYLOAD_OFFSET];
				uint16_t phase = dataBuffer[PHASE_MSB_PAYLOAD_OFFSET] << 8 | dataBuffer[PHASE_LSB_PAYLOAD_OFFSET];
				uint16_t amplitude = dataBuffer[AMP_MSB_PAYLOAD_OFFSET] << 8 | dataBuffer[AMP_LSB_PAYLOAD_OFFSET];	
				
				write_RDAC(dev, amplitude);
				
				// Send 'OK' if command is received
				uint8_t resp[11];
				sprintf(resp, "OK DEV(%d)\n", dev);
				CDC_Transmit_FS(resp, sizeof(resp));				
			}
				break;
			case CHANGE_SPEAKER_FREQUENCY:
			{
				uint8_t dev = dataBuffer[DEV_PAYLOAD_OFFSET];
				uint16_t frequency = dataBuffer[FREQ_MSB_PAYLOAD_OFFSET] << 8 | dataBuffer[FREQ_LSB_PAYLOAD_OFFSET];
				uint16_t phase = dataBuffer[PHASE_MSB_PAYLOAD_OFFSET] << 8 | dataBuffer[PHASE_LSB_PAYLOAD_OFFSET];
				uint16_t amplitude = dataBuffer[AMP_MSB_PAYLOAD_OFFSET] << 8 | dataBuffer[AMP_LSB_PAYLOAD_OFFSET];	
				
				setFrequencyRegister(dev, 0, frequency);
				
				// Send 'OK' if command is received
				uint8_t resp[11];
				sprintf(resp, "OK DEV(%d)\n", dev);
				CDC_Transmit_FS(resp, sizeof(resp));				
			}
				break;
			case CHANGE_SPEAKER_PHASE:
			{
				uint8_t dev = dataBuffer[DEV_PAYLOAD_OFFSET];
				uint16_t frequency = dataBuffer[FREQ_MSB_PAYLOAD_OFFSET] << 8 | dataBuffer[FREQ_LSB_PAYLOAD_OFFSET];
				uint16_t phase = dataBuffer[PHASE_MSB_PAYLOAD_OFFSET] << 8 | dataBuffer[PHASE_LSB_PAYLOAD_OFFSET];
				uint16_t amplitude = dataBuffer[AMP_MSB_PAYLOAD_OFFSET] << 8 | dataBuffer[AMP_LSB_PAYLOAD_OFFSET];	
			
				setPhaseRegister(dev, 0, phase);
				
				// Send 'OK' if command is received
				uint8_t resp[11];
				sprintf(resp, "OK DEV(%d)\n", dev);
				CDC_Transmit_FS(resp, sizeof(resp));				
			}
				break;
			default:
				break;
		}

		// HAL_Delay(10);
//		
//		/*
//		uint8_t test = 0;
//		uint8_t testBuffer[4] = {0};
//		
//		uint8_t numBytes = 0;
//		bool endCharacter = false;
//		
//		while (numBytes < 4 && !endCharacter){
//			if (CDC_Read_FS(&test, 1) == 0){
//				testBuffer[numBytes] = test;
//				numBytes++;
//				
//				if (test == '\n'){
//					endCharacter = true;
//				}
//			}
//		}
//			
//		CDC_Transmit_FS(testBuffer, sizeof(testBuffer));	
//		HAL_Delay(1000);
//		*/		
//		
//		/*	
//		if (CDC_Read_FS(&test, 1) == 0){
//			uint8_t buffer[] = "Hello, World!\r\n";
//			CDC_Transmit_FS(buffer, sizeof(buffer));
//						
//		}
//		HAL_Delay(1000);	
//		*/

//	setFrequencyRegister(0x0D, 0, 40000);
//	setFrequencyRegister(0x0F, 0, 40000);
//	setFrequencyRegister(0x05, 0, 40000);
//	setFrequencyRegister(0x07, 0, 40000);
//	setFrequencyRegister(0x09, 0, 40000);
//	setFrequencyRegister(0x0B, 0, 40000);
//	setFrequencyRegister(0x01, 0, 40000);
//	setFrequencyRegister(0x03, 0, 40000);
//	setFrequencyRegister(0x00, 0, 40000);
//	setFrequencyRegister(0x02, 0, 40000);
//	
//	setPhaseRegister(0x03, 0, 0);

//	HAL_Delay(2000);
//	
//	setPhaseRegister(0x01, 0, 90);
//	setPhaseRegister(0x09, 0, 90);
//	setPhaseRegister(0x0B, 0, 90);
//	setPhaseRegister(0x05, 0, 90);
//	setPhaseRegister(0x07, 0, 90);
//	setPhaseRegister(0x0D, 0, 90);
//	setPhaseRegister(0x0F, 0, 90);
//	setPhaseRegister(0x00, 0, 90);
//	setPhaseRegister(0x02, 0, 90);
//	HAL_Delay(2000);
//	setPhaseRegister(0x01, 0, 0);
//	setPhaseRegister(0x09, 0, 0);
//	setPhaseRegister(0x0B, 0, 0);
//	setPhaseRegister(0x05, 0, 0);
//	setPhaseRegister(0x07, 0, 0);
//	setPhaseRegister(0x0D, 0, 0);
//	setPhaseRegister(0x0F, 0, 0);
//	setPhaseRegister(0x00, 0, 0);
//	setPhaseRegister(0x02, 0, 0);
    /* USER CODE END WHILE */

    /* USER CODE BEGIN 3 */
  }
  /* USER CODE END 3 */
}

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


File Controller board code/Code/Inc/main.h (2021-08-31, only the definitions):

#define S1_M4A_Pin GPIO_PIN_2
#define S1_M4A_GPIO_Port GPIOE
#define B1_Pin GPIO_PIN_13
#define B1_GPIO_Port GPIOC
#define MUX_EN_B_Pin GPIO_PIN_0
#define MUX_EN_B_GPIO_Port GPIOF
#define PSELECT_Pin GPIO_PIN_0
#define PSELECT_GPIO_Port GPIOA
#define LD1_Pin GPIO_PIN_0
#define LD1_GPIO_Port GPIOB
#define S0_M16_B_Pin GPIO_PIN_0
#define S0_M16_B_GPIO_Port GPIOG
#define S1_M16_B_Pin GPIO_PIN_1
#define S1_M16_B_GPIO_Port GPIOG
#define FSELECT_Pin GPIO_PIN_15
#define FSELECT_GPIO_Port GPIOE
#define S0_M16_Pin GPIO_PIN_12
#define S0_M16_GPIO_Port GPIOB
#define LD3_Pin GPIO_PIN_14
#define LD3_GPIO_Port GPIOB
#define S1_M16_Pin GPIO_PIN_15
#define S1_M16_GPIO_Port GPIOB
#define STLINK_RX_Pin GPIO_PIN_8
#define STLINK_RX_GPIO_Port GPIOD
#define STLINK_TX_Pin GPIO_PIN_9
#define STLINK_TX_GPIO_Port GPIOD
#define USB_OTG_FS_PWR_EN_Pin GPIO_PIN_10
#define USB_OTG_FS_PWR_EN_GPIO_Port GPIOD
#define S0_M4A_Pin GPIO_PIN_11
#define S0_M4A_GPIO_Port GPIOD
#define USB_OTG_FS_OVCR_Pin GPIO_PIN_7
#define USB_OTG_FS_OVCR_GPIO_Port GPIOG
#define S2_M16_Pin GPIO_PIN_7
#define S2_M16_GPIO_Port GPIOC
#define S1_M16A15_Pin GPIO_PIN_15
#define S1_M16A15_GPIO_Port GPIOA
#define RESET_Pin GPIO_PIN_11
#define RESET_GPIO_Port GPIOC
#define S3_M16_B_Pin GPIO_PIN_0
#define S3_M16_B_GPIO_Port GPIOD
#define S2_M16_B_Pin GPIO_PIN_1
#define S2_M16_B_GPIO_Port GPIOD
#define SLEEP_Pin GPIO_PIN_2
#define SLEEP_GPIO_Port GPIOD
#define MUX_EN_Pin GPIO_PIN_3
#define MUX_EN_GPIO_Port GPIOB
#define S3_M16_Pin GPIO_PIN_5
#define S3_M16_GPIO_Port GPIOB
#define LD2_Pin GPIO_PIN_1
#define LD2_GPIO_Port GPIOE

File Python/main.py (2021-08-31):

#  ____  ____      _    __  __  ____ ___
# |  _ \|  _ \    / \  |  \/  |/ ___/ _ \
# | | | | |_) |  / _ \ | |\/| | |  | | | |
# | |_| |  _ <  / ___ \| |  | | |__| |_| |
# |____/|_| \_\/_/   \_\_|  |_|\____\___/
#                           research group
#                             dramco.be/
#
#  KU Leuven - Technology Campus Gent,
#  Gebroeders De Smetstraat 1,
#  B-9000 Gent, Belgium
#
#         File: main.py
#      Created: 09-07-2021
#       Author: Chesney Buyle
#      Version: 1.0
#
#  Description: Phased Array Measurements
#      Array calibration: amplitude and phase
#      Beam pattern measurements

from controller import *
from daq import *
from stepper import *
import time
import keyboard
from scipy.optimize import curve_fit

devices = [0x03, 0x01, 0x0B, 0x0A, 0x07, 0x05, 0x0F, 0x0D, 0x02, 0x08]
frequencies = [10000, 11000, 12000, 13000, 14000, 15000, 16000, 17000, 18000, 19000, 20000, 21000, 22000, 23000, 24000,
               25000, 26000, 27000, 28000, 29000, 30000, 31000, 32000, 33000, 34000, 35000]
# frequencies = [31000, 32000]

default_rpot = 12000

# Amplitude calibration settings
db_rms_deviation = 0.5  # dB

# Phase calibration settings
min_phase_calibration = -140
max_phase_calibration = 140
phase_calibration_step = 5

sleep_time_after_speaker_change = 0.2

steering_angle = 70

current_angle_az = 0
turn_degree_az = 1
total_turns_one_revolution_from_angle_az = round(360 / turn_degree_az)
total_turns_one_revolution_from_angle_el = 1
rms_vs_angle = np.zeros((total_turns_one_revolution_from_angle_el, total_turns_one_revolution_from_angle_az))

array_configuration = "1x10"
freq = "25kHz"
dist = "0_75m"
beam_angle = "0"

# Data files
version = "anechoic"
f_name_uncalibrated_speaker_sweep = "uncal_speaker_sweep_" + version + ".txt"
f_name_uncalibrated_speaker_sweep_min = "uncal_speaker_sweep_min_" + version + ".txt"
f_name_uncalibrated_speaker_sweep_max = "uncal_speaker_sweep_max_" + version + ".txt"
f_name_uncalibrated_speaker_sweep_std = "uncal_speaker_sweep_std_" + version + ".txt"
f_name_uncalibrated_speaker_sweep_info = "uncal_speaker_sweep_info_" + version + ".txt"

f_name_calibrated_speaker_sweep = "cal_speaker_sweep_" + version + ".txt"
f_name_calibrated_speaker_sweep_min = "cal_speaker_sweep_min_" + version + ".txt"
f_name_calibrated_speaker_sweep_max = "cal_speaker_sweep_max_" + version + ".txt"
f_name_calibrated_speaker_sweep_std = "cal_speaker_sweep_std_" + version + ".txt"
f_name_calibrated_speaker_sweep_info = "cal_speaker_sweep_info_" + version + ".txt"

f_name_calibrated_rpot = "calibrated_rpot_" + version + ".txt"
f_name_error_file_response_calibration = "error_" + version + ".txt"

f_name_calibrated_phase_shifts = "calibrated_phase_shifts_" + version + ".txt"
f_name_calibrated_phase_shifts_info = "calibrated_phase_shifts_info_" + version + ".txt"

f_name_beam_pattern_base = "beampattern_" + str(array_configuration) + "_config_" + str(freq) + "_" + str(dist) + \
                           "_beamangle_" + str(beam_angle) + "_" + str(version)


# First, let's calibrate the speaker array
# Step 1: amplitude calibration
# Step 2: phase calibration

# Amplitude calibration
# First, we measure the responses of the speaker elements over a certain frequency range
# The speaker with the lowest response at a certain frequency is used as reference
# and all speakers are amplitude calibrated towards the same response


def calibrate_amplitude():
    # Step 1: measure speaker responses
    measure_frequency_response()

    # Step 2: calibrate speaker responses
    calibrate_speaker_responses()

    # Step 3: sweep calibrated speaker responses
    measure_calibrated_frequency_response()


def calibrate_phase():
    # Step 1: measure phase offset w.r.t. speaker 0
    measure_phase_offsets()

    # Step 2: apply fitting to calculate the phase offsets
    calculate_phase_offsets()


def measure_phase_offsets():
    global f_name_calibrated_speaker_sweep_info
    global f_name_calibrated_speaker_sweep
    global sleep_time_after_speaker_change
    global version
    global min_phase_calibration
    global max_phase_calibration
    global phase_calibration_step

    # Speaker 0 is used as reference speaker
    # The other speakers are enabled one by one separately and the phase is shifted between [0° and 360°]
    # The resulting response should be a sine wave, and the phase offset is calculated through fitting

    # First, we read the info data from the amplitude calibration measurements
    f_info = open(f_name_calibrated_speaker_sweep_info, "r")
    str_devices = f_info.readline().rstrip('\n').lstrip("devices: ").replace(" ", "")
    l_devices = np.array(str_devices.split(",")).astype(np.ushort)
    print(l_devices)
    str_frequencies = f_info.readline().rstrip('\n').lstrip("frequencies: ").replace(" ", "")
    l_frequencies = np.array(str_frequencies.split(",")).astype(np.ushort)
    print(l_frequencies)
    f_info.close()

    # Also get the calibrated RPOT values
    calibrated_rpot = np.loadtxt(f_name_calibrated_rpot, ndmin=2).astype(np.ushort)
    print(calibrated_rpot.dtype)

    # The phase will be varied in the following interval
    min_phase = min_phase_calibration
    max_phase = max_phase_calibration
    phase_step = phase_calibration_step

    phases = np.linspace(min_phase, max_phase,
                         int(np.rint((np.abs(min_phase) + np.abs(max_phase)) / phase_step) + 1))

    # Disable all speaker elements
    disable_all_speaker_elements_software()
    time.sleep(2)

    for f, freq in enumerate(l_frequencies):
        # For now, we target only one single frequency
        if int(freq) == 25000:
            print("Phase cal. frequency: " + str(freq))

            # We enable one speaker element as reference speaker
            # This will be speaker 0
            enable_specific_speaker_element(l_devices[0])
            change_speaker_settings(l_devices[0], freq, 0, calibrated_rpot[0, f])
            time.sleep(sleep_time_after_speaker_change)

            # Now we enable the other speakers one by one and sweep the phase
            for d, dev in enumerate(l_devices):
                if d != 0:
                    rms_tmp = np.zeros(len(phases))

                    # Ask if speaker is connected
                    print("Sweep device: " + str(d))
                    print("Press enter to continue")
                    while not keyboard.is_pressed('enter'):
                        pass

                    # Enable second speaker element
                    enable_specific_speaker_element(l_devices[d])
                    time.sleep(1)
                    change_speaker_settings(l_devices[d], freq, 0, calibrated_rpot[d, f])
                    time.sleep(sleep_time_after_speaker_change)

                    for p, phase_dif in enumerate(phases):
                        print("Phase shift: " + str(phase_dif))
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

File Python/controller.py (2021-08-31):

#  ____  ____      _    __  __  ____ ___
# |  _ \|  _ \    / \  |  \/  |/ ___/ _ \
# | | | | |_) |  / _ \ | |\/| | |  | | | |
# | |_| |  _ <  / ___ \| |  | | |__| |_| |
# |____/|_| \_\/_/   \_\_|  |_|\____\___/
#                           research group
#                             dramco.be/
#
#  KU Leuven - Technology Campus Gent,
#  Gebroeders De Smetstraat 1,
#  B-9000 Gent, Belgium
#
#         File: controller.py
#      Created: 09-07-2021
#       Author: Chesney Buyle
#      Version: 1.0
#
#  Description: controller commands to NUCLEO board

import struct
import serial

# Virtual COM Port (VCP) of the NUCLEO board
ser = serial.Serial('COM6', 115200, timeout=1)


def disable_all_speaker_elements():
    # Sleep command = command 1
    payload_list = [6, 0, 0, 0, 0]

    # Send payload to VCP
    payload = struct.pack(">BBHHH", *payload_list)  # big endian, [uchar, ushort, ushort, ushort]
    ser.write(payload)
    if ser.inWaiting():
        print(ser.readline())


def disable_all_speaker_elements_software():
    # Sleep command = command 1
    payload_list = [8, 0, 0, 0, 0]

    # Send payload to VCP
    payload = struct.pack(">BBHHH", *payload_list)  # big endian, [uchar, ushort, ushort, ushort]
    ser.write(payload)
    if ser.inWaiting():
        print(ser.readline())


def enable_all_speaker_elements():
    # Sleep command = command 1
    payload_list = [7, 0, 0, 0, 0]

    # Send payload to VCP
    payload = struct.pack(">BBHHH", *payload_list)  # big endian, [uchar, ushort, ushort, ushort]
    ser.write(payload)
    if ser.inWaiting():
        print(ser.readline())


def enable_all_speaker_elements_software():
    # Sleep command = command 1
    payload_list = [9, 0, 0, 0, 0]

    # Send payload to VCP
    payload = struct.pack(">BBHHH", *payload_list)  # big endian, [uchar, ushort, ushort, ushort]
    ser.write(payload)
    if ser.inWaiting():
        print(ser.readline())


def disable_specific_speaker_element(dev):
    # Sleep command = command 1
    payload_list = [1, dev, 0, 0, 0]

    # Send payload to VCP
    payload = struct.pack(">BBHHH", *payload_list)  # big endian, [uchar, ushort, ushort, ushort]
    ser.write(payload)
    if ser.inWaiting():
        print(ser.readline())


def enable_specific_speaker_element(dev):
    # Enable command = command 1
    payload_list = [5, dev, 0, 0, 0]

    # Send payload to VCP
    payload = struct.pack(">BBHHH", *payload_list)  # big endian, [uchar, ushort, ushort, ushort]
    ser.write(payload)
    if ser.inWaiting():
        print(ser.readline())


def change_speaker_settings(dev, freq, phase, amp):
    # Change speaker settings = command 0
    payload_list = [0, dev, freq, phase, amp]
    payload = struct.pack(">BBHHH", *payload_list)  # big endian, [uchar, ushort, ushort, ushort]

    ser.write(payload)
    if ser.inWaiting():
        pass
        # print(ser.readline())


def change_speaker_vga(dev, amp):
    # Change speaker settings = command 0
    payload_list = [2, dev, 0, 0, amp]
    payload = struct.pack(">BBHHH", *payload_list)  # big endian, [uchar, ushort, ushort, ushort]

    ser.write(payload)
    if ser.inWaiting():
        print(ser.readline())


def change_speaker_frequency(dev, freq):
    # Change speaker settings = command 0
    payload_list = [3, dev, freq, 0, 0]
    payload = struct.pack(">BBHHH", *payload_list)  # big endian, [uchar, ushort, ushort, ushort]

    ser.write(payload)
    if ser.inWaiting():
        print(ser.readline())


def change_speaker_phase(dev, phase):
    # Change speaker settings = command 0
    payload_list = [4, dev, 0, phase, 0]
    payload = struct.pack(">BBHHH", *payload_list)  # big endian, [uchar, ushort, ushort, ushort]

    ser.write(payload)
    if ser.inWaiting():
        print(ser.readline())

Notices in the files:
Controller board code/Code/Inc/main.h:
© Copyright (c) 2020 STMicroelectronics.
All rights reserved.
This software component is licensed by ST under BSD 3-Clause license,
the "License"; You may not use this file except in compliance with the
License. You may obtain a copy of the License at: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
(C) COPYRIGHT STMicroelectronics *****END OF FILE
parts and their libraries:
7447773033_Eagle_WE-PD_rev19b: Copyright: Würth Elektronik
